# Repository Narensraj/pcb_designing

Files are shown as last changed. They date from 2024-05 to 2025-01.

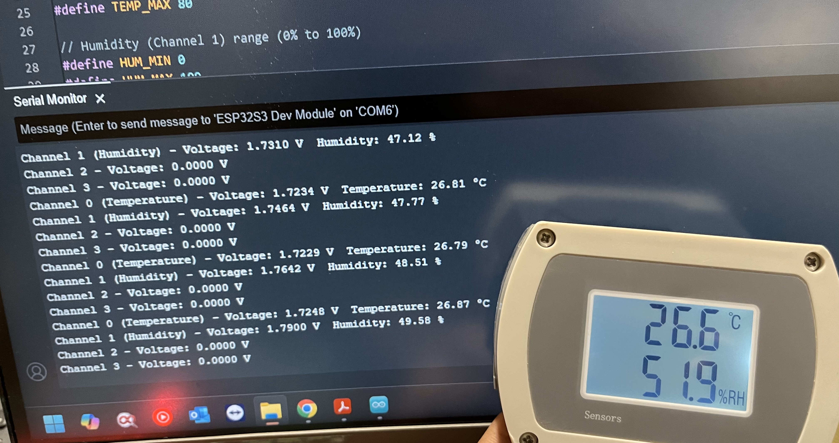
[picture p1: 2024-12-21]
Project_G/Test codes and examples/Analog_Input/TempHumid Sensor.jpg

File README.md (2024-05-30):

# ESP32 Relay Board

## Overview

This repository contains the design and documentation for an ESP32 relay board created using EasyEDA. It comprises various components such as AC to DC converter, voltage regulator, ESP32 microcontroller, USB to UART interface, relay control, RGB LED control, and miscellaneous components.

## Components

### AC to DC Converter

- **Module:** HLK-PM01
- **Output:** 5V from AC mains

### Voltage Regulator (AMS1117-3.3)

- **Function:** Converts 5V to 3.3V
- **Usage:** Provides power to the ESP32 and other 3.3V components

### Capacitors

- **Types:** Decoupling capacitors (220 µF, 10 µF, and 100 nF)
- **Purpose:** Stabilize the voltage supply around the voltage regulator

### ESP32 Microcontroller

- **Model:** ESP32-S3-WROOM-1 (U3)
- **Functionality:** Central microcontroller unit
- **Features:**
  - GPIO Connections for various components
  - Reset and Boot Buttons for manual control

### USB to UART Interface

- **Model:** CP2102-GMR (U16)
- **Functionality:** USB to UART bridge for programming and serial communication
- **Components:**
  - Includes RTS, DTR signals, and USB data lines (D+, D-)

### Relay Control

- **Relays:** ALQ105
- **Control:** GPIO pins through transistors (MMSS8050-H-TP) and optocouplers (CYPC817)
- **Supporting Components:** Transistors, resistors, and optocouplers for relay coil control and isolation

### RGB LED Control

- **LED Type:** WS2812B
- **Control:** Connected to a GPIO pin for RGB LED control

### Miscellaneous Components

- **Test Points:** Provided for 3.3V, 5V, and ground for easy debugging
- **Indicator LEDs:** With current limiting resistors to indicate power status and other signals
- **Mounting Holes:** For securing the PCB

## License

This project is licensed under no-one you can freely use the schematics and pcb layout.

And remember, when life throws you a relay, just switch it on and keep the circuit flowing! 😉🔌

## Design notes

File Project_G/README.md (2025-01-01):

# GController: ESP32-S3-Based Controller System

## Overview
The **GController** is a feature-rich embedded system designed using the **ESP32-S3** microcontroller. It integrates multiple peripherals, sensors, and interfaces, making it an ideal choice for industrial automation, IoT, and control system applications. This repository documents the hardware design, PCB layout, and related details for the GController system.

---

## Hardware Design

### PCB Specifications
- **Multi-layer PCB**:
  - Dedicated power and ground planes for noise reduction.
- **Connector Layouts**:
  - Clearly marked connections for peripherals, power, and sensors.
  - Separate connectors for high-current and low-current devices.
- **Thermal Considerations**:
  - Adequate spacing and heat management for power MOSFETs and regulators.

### Key ICs and Components

1. **Core Controller**:
   - **ESP32-S3-WROOM-1U-N16R8**: Dual-core processor with Wi-Fi, Bluetooth 5.0, and extensive GPIO support for SPI, I2C, UART, ADC, and DAC.  
     16 MB Flash and 8 MB PSRAM for seamless multitasking and data handling.

2. **Power Management**:
   - **XL4015**: High-efficiency buck converter for 12V output.
   - **XL1507 & B0505S**: 5V buck converter for powering isolated systems.
   - **ADM7172**: Low-dropout regulator for 3.3V output.
   - **LM74500**: Reverse polarity protection for stable operation.

3. **Communication Interfaces**:
   - **RS485** communication with **SP485EEN-L/TR** transceiver.
   - LoRa header for long-range wireless communication.
   - USB Type-C interface with ESD protection.

4. **Peripheral Interfaces**:
   - **Analog Inputs**: 4 channels (4-20mA) with **ADS1115** (16-bit ADC).
   - **Analog Outputs**: 2 channels (0-10V) driven by **GP8413** (15-bit DAC).
   - **Digital Inputs**: 6 optocoupler-based channels (EL357N), supporting 3-32V input.
   - **Digital Outputs**: 8 MOSFET-driven channels (IRF5305STRLPBF), handling 5-36V @ 5A, and 2 **ALQ105** Relay channels.

5. **Integrated Sensors and Storage**:
   - **BMP280**: Onboard temperature and pressure monitoring.
   - **DS3231 RTC**: Real-time clock for precise scheduling.
   - **Storage**:
     - **W25N01GVZEIG** SPI NAND Flash.
     - SD card slot for extended storage.

6. **User Interface**:
   - 7-inch touchscreen support with dedicated connector.
   - RGB LED indicators (WS2812B) for system status.
   - Built-in buzzer for notifications.

7. **Pilot Lamps and Headers**:
   - Pilot lamps for "Running," "Alarm," and "Stopped" statuses.
   - Dedicated headers for power, UART, and LoRa.

---

## Documentation
- [Schematic](./Documents/Schematic.pdf)
- [PCB Layout](./Documents/PCB.pdf)

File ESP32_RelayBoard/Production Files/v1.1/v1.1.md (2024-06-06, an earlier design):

# v1.1

Couple of traces had acute angle. Which is been changed to 45°.

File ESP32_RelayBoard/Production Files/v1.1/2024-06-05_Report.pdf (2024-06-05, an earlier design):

## HQDFM Design for Manufacture(DFM) Report

### File name: 2024-06-05

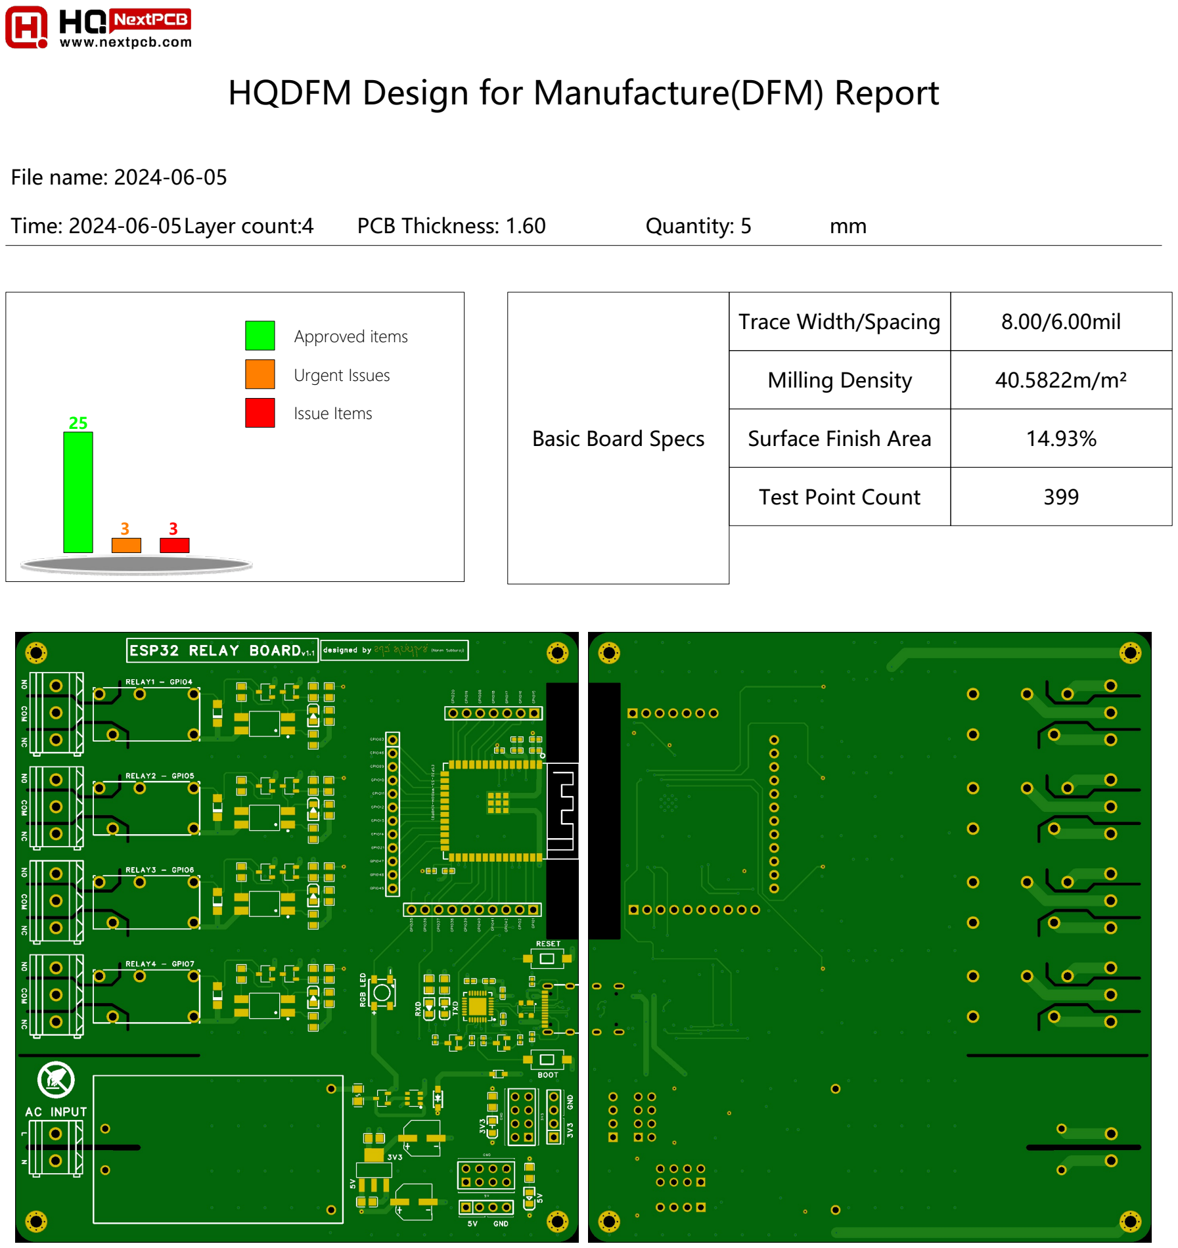
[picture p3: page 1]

Time: 2024-06-05Layer count:4 | PCB Thickness: 1.60 | Quantity: 5
mm

Approved items

Urgent Issues

Issue Items 25

3 3

Basic Board Specs | Trace Width/Spacing | 8.00/6.00mil
| Milling Density | 40.5822m/m²
| Surface Finish Area | 14.93%
| Test Point Count | 399

Type | Category | No. of Checks | Result
| Open/Shorts (IPC) | 1 | Fail
| Signal Integrity | 4 | Pass
| Smallest Trace Width | 1 | Pass 3
| Smallest Trace Spacing | 3 | Pass 161
| SMD Pad Spacing | 1 | Pass
| Pad Size | 3 | Pass 30
| Hatched Copper Pour | 2 | Pass
| Annular Ring Size | 2 | Pass 6 , Fail 1
| Drill to Copper | 5 | Pass 630 , Fail 2
| Copper-to-Board Edge | 2 | Pass 132 , Fail 34
| Holes on SMD Pads | 4 | Pass
PCB Drilling Analysis | Drill Diameter | 8 | Pass 41 , Fail 1
| Drill Spacing | 4 | Pass 18
| Drill to Board Edge | 4 | Pass
| Drill Hole Density | 1 | Pass
| Special Drill Holes | 2 | Pass
| Drill Hole Errors | 3 | Pass
PCB Solder Mask Analysis | Solder Mask Dam | 2 | Pass 12
| Missing SMask Opening | 1 | Pass
| Solder Paste Area | 1 | Pass
PCB Silk Analysis | Silkscreen Spacing | 1 | Pass 5 , Fail 14

PCB Trace Analysis

PCBA Component Analysis | Component Spacing | 1 | Fail
| Comp.-to-Board-Edge | 3 | Fail
| Componet Silkscreen Spacing | 0 | Fail
| Pad Count Mismatch | 2 | Fail
| Designator Length | 0 | Fail
| Double-sided Components | 1 | Pass
ComponentClearanceAnalysis | 1 | Pass
PCBA Pin Analysis | Pin-to-SMD Pad | 7 | Fail
| Through-hole Pins | 9 | Fail
| Pressfit Pins | 4 | Fail
PCBA Pad Analysis | Chip Pad | 60 | Fail
| Pad-Trace Connections | 4 | Pass 302 , Fail 44
PCBA Fiducial Analysis | Fiducial Count | 1 | Fail
| Fiducial Analysis | 3 | Pass

ID | Check | Limits | Value | Issue | Image | Position | Qty | Level

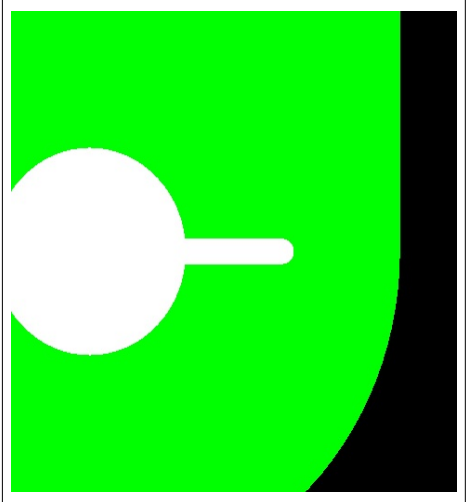
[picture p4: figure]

1

Annular

### Ring Size_PTH

Annular

### Ring

6,7,8

0.15

mm

PTH annular rings 6.10mil
mil in size were detected in your design. This could
increase the risk of
tangency or breakouts, which decrease

manufacturing efficiency
and yield, and affect the
reliability of the boards. It is recommended that PTH
Pad Rings have a width of
at least 6 mil.
96.98,-109.87 | 1 | Warnin g

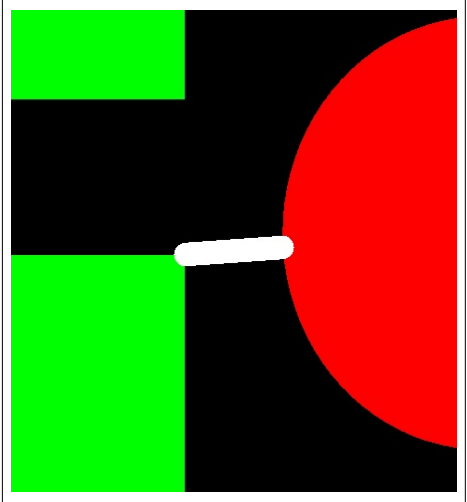
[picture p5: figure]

2

### Drill to

Copper_NP
TH-to- Copper

8,10,12

0.17

mm

The NPTH to copper
spacing should be at least

### 8 mil (ideally 12 mil). Spacing less than this could

increase the risk of defects such as exposed copper, which decrease

manufacturing efficiency
and yield, and affect the
reliability of the boards. The NPTH to copper

spacing in your design is
only 6.75mil. It is
recommended to increase
the spacing to at least 12 mil.
100.26,-73.95 | 1 | Risk

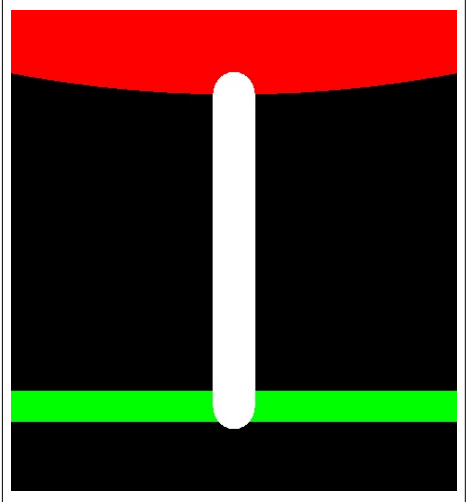
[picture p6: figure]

3

Copper-to- Board

### Edge_Cop

per-to- Board

### Edge

8,15,20

0.26

mm

Copper-to-edge spacing of
10.10mil was detected in
your design.This could
increase the risk of
exposed copper on the
edge of the boards or
damaged traces/pads, which decrease

manufacturing efficiency
and yield, and affect the
reliability of the boards. It is recommended to
increase the spacing to at least 0.4 mm for edge
routing and for v-cuts (v- cut spacing may depends

on board thickness).

15.82,-30.70 | 4 | Warnin
| | g

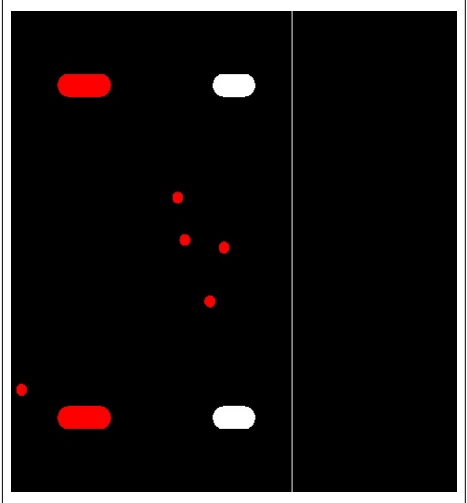
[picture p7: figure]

4

### Drill

Diameter_S
lot Aspect
Ratio

12,10,8

0.31

mm

Slots with aspect ratio of 2.00 were detected in your design. This could increase the risk of incomplete

### drilling of the slot, which

decrease manufacturing
efficiency and yield, and

### affect the reliability of the

boards. The ratio should be increased to at least 2:1

104.37,-71.03 | 1 | Warnin g

5

### Silkscre

e

n
S
p

acin
g

_

S

### old

er Mask-to- Silkscreen

4,5,6

0.0

0

m

# m For m ost factories, th

e
| minim
u

m silkscre
e

n to solder mask spacing requirement is at least 8 mil. Failure to meet the factory's requirements could result in part of the silkscreen being removed or being printed directly o

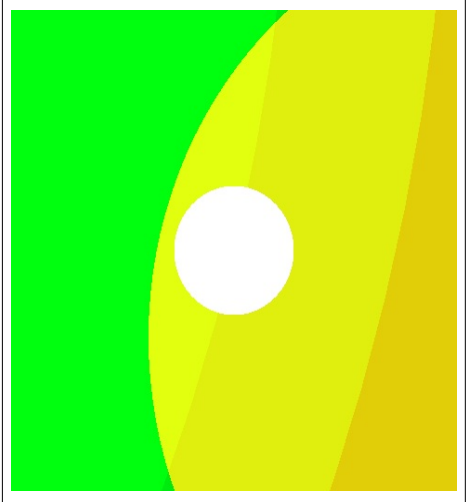
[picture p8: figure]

n the pads, which decrease manufacturing efficiency and yield, and affect the reliability of the boards. Silkscreen to solder mask spacing of 0 mil were detected in your design. It is recommended to increase the spacing to at least 12 mil. | 10
5.2

6,-7
5.5
0 | 1 | Risk

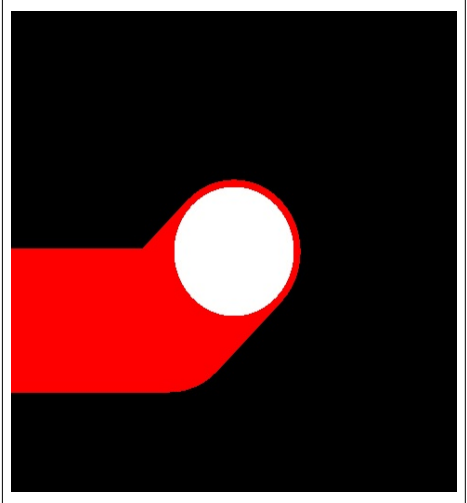
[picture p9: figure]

6

P
a

d-Trace
C
o

n

n

ectio

ns _

T

H

T
P
a
d-Trace Width | -,-,- | N ot analy

z
| | e
d | If th
e trace

width is gre
ater than 100.00% of the width of the solder pad, there will be increased thermal dissipation to the connected copper during soldering that may increase solder defects such as cold solder joints. It is recommended to reduce the trace width near the pad (necking down). | 16.9

5,-9

3.5

3

2

### Risk

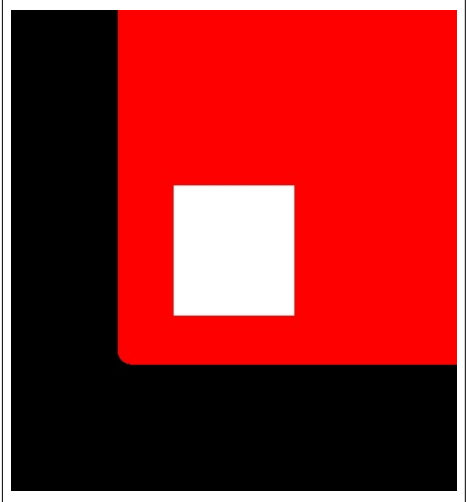
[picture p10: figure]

7

P
a

d-Trace
C
o

n

n

ectio

ns _

S
M

D
P
a
d-Trace Width | -,-,- | N ot analy

z
| | e
d | If th
e trace

width is gre
ater than 100.00% of the width of the solder pad, there will be increased thermal dissipation to the connected copper during soldering that may increase solder defects such as cold solder joints. It is recommended to reduce the trace width near the pad (necking down). | 8

9.4

7,-3

3.6
4

3
5

### Risk

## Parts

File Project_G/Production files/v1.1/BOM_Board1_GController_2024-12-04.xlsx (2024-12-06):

No. | Quantity | Comment | Designator | Footprint | Value | Manufacturer Part | Manufacturer | Supplier Part | Supplier | Layer
1 | 1 | CR2032-BS-6-1 | B1 | BAT-TH_CR2032-BS-6-1 |  | CR2032-BS-6-1 | Q&J | C70377 | LCSC | T
2 | 1 | 2.7kHz | BUZZER1 | BUZ-SMD_4P-L8.5-W8.5-P8.50-BR | 2.7kHz | MLT-8530 | 华能 | C94599 | LCSC | T
3 | 1 | 4.7nF | C1 | C1206 | 4.7nF | 1206B472K102NT | FH(风华) | C9192 | LCSC | T
4 | 4 | 1uF | C2,C7,C9,C11 | C0805 | 1uF | 0805B105K500NT | FH(风华) | C215803 | LCSC | T
5 | 2 | 330nF | C3,C16 | C1206 | 330nF | CC1206KRX7R9BB334 | YAGEO(国巨) | C274377 | LCSC | T
6 | 2 | 100nF | C4,C73 | C0603 | 100nF | CL10B104KA8NNNC | SAMSUNG(三星) | C1590 | LCSC | T
7 | 2 | 2.2uF | C5,C74 | C1210 | 2.2uF | CL32B225KCJSNNE | SAMSUNG(三星) | C55151 | LCSC | T
8 | 2 | 220uF | C6,C75 | CAP-SMD_BD10.0-L10.3-W10.3-LS11.3-FD | 220uF | RVT1H221M1010 | ROQANG(容强) | C72499 | LCSC | T
9 | 1 | 330uF | C8 | CAP-SMD_BD6.3-L6.6-W6.6-LS7.3-FD | 330uF | GVM1E331M0607 | HONOR(荣誉) | C2980171 | LCSC | T
10 | 1 | 470uF | C10 | CAP-SMD_BD12.5-L13.0-W13.0-FD | 470uF | VT1H471MI135000CE0 | HUAWEI(华威集团) | C191227 | LCSC | T
11 | 1 | 330uF | C12 | CAP-SMD_BD10.0-L10.3-W10.3-LS11.3-FD | 330uF | RVE1V331M1010 | HONOR(荣誉) | C88682 | LCSC | T
12 | 2 | 10uF | C13,C14 | C0805 | 10uF | CL21A106KOQNNNE | SAMSUNG(三星) | C1713 | LCSC | T
13 | 1 | 100nF | C15 | C0805 | 100nF | C0805B104K500NT | TORCH(火炬) | C476766 | LCSC | T
14 | 2 | 4.7uF | C17,C18 | C0805 | 4.7uF | HGC0805R7475K500NSLJ | Chinocera(华瓷) | C7472970 | LCSC | T
15 | 15 | 1uF | C19,C21,C23,C24,C28,C31,C32,C36,C37,C39,C44,C46,C55,C60,C68 | C0603 | 1uF | C0603X5R105K250NT | SANYEAR(叁叶源) | C466771 | LCSC | T
16 | 7 | 100nF | C20,C22,C25,C27,C29,C33,C35 | C0603 | 100nF | CC0603KRX7R9BB104 | YAGEO(国巨) | C14663 | LCSC | T
17 | 3 | 10uF | C26,C30,C34 | C0805 | 10uF | CL21A106KAYNNNE | SAMSUNG(三星) | C15850 | LCSC | T
18 | 14 | 100nF | C38,C45,C47,C48,C49,C50,C52,C54,C57,C59,C61,C69,C70,C71 | C0603 | 100nF | CL10B104KB8NNNC | SAMSUNG(三星) | C1591 | LCSC | T
19 | 3 | 100nF | C40,C43,C64 | C0402 | 100nF | GRM155R71H104KE14D | muRata(村田) | C77020 | LCSC | T
20 | 2 | 10uF | C41,C42 | C0402 | 10uF | CL05A106MQ5NUNC | SAMSUNG(三星) | C15525 | LCSC | T
21 | 1 | 1nF | C51 | C0603 | 1nF | 0603B102K101CT | Walsin(华新科) | C77438 | LCSC | T
22 | 1 | 1nF | C53 | C1206 | 1nF | GR431BR7LA102KW66L | muRata(村田) | C161353 | LCSC | T
23 | 2 | 10uF | C56,C58 | C0603 | 10uF | GRM188R61E106KA73D | muRata(村田) | C344022 | LCSC | T
24 | 4 | 10pF | C62,C63,C66,C67 | C0603 | 10pF | CC0603JRNPO9BN100 | YAGEO(国巨) | C106245 | LCSC | T
25 | 1 | 1uF | C65 | C0402 | 1uF | HGC0402R5105K250NTEJ | Chinocera(华瓷) | C7472946 | LCSC | T
26 | 2 | 330nF | C72,C76 | C1206 | 330nF | 1206B334K500NT | FH(风华) | C1865 | LCSC | T
27 | 1 | DB2ERC-5.08-3P-OG | CN1 | CONN-TH_3P-P5.08_DB2ERC-5.08-3P-OG |  | DB2ERC-5.08-3P-OG | DORABO(地博电气) | C430435 | LCSC | T
28 | 23 | DB2ERC-5.08-2P-GN | CN2,CN3,CN4,CN5,CN6,CN7,CN8,CN9,CN10,CN11,CN12,CN13,CN14,CN15,CN16,CN17,CN18,CN19,CN20,CN21,CN24,CN25,CN26 | CONN-TH_2P-P5.08_DB2ERC-5.08-2P |  | DB2ERC-5.08-2P-GN | DORABO(地博电气) | C395737 | LCSC | T
29 | 2 | DB2ERC-5.08-3P-BK | CN22,CN23 | CONN-TH_3P-P5.08_DB2ERC-5.08-3P-BK |  | DB2ERC-5.08-3P-BK | DORABO(地博电气) | C430440 | LCSC | T
30 | 2 | PMEG6030ETPX | D1,D3 | SOD-128_L3.7-W2.5-LS4.7-RD |  | PMEG6030ETPX | Nexperia(安世) | C458168 | LCSC | T
31 | 1 | PRTR5V0U2X,215 | D2 | SOT-143_L2.9-W1.3-P1.92-LS2.3-BR |  | PRTR5V0U2X,215 | Nexperia(安世) | C12333 | LCSC | T
32 | 2 | SMBJ33CA | D4,D42 | SMB_L4.3-W3.6-LS5.4-BI |  | SMBJ33CA | Brightking(君耀电子) | C78420 | LCSC | T
33 | 1 | B540C-13-F | D5 | SMC_L7.1-W6.2-LS8.1-RD |  | B540C-13-F | DIODES(美台) | C72264 | LCSC | T
34 | 1 | B330B-13-F | D6 | SMB_L4.6-W3.6-LS5.3-RD |  | B330B-13-F | DIODES(美台) | C134450 | LCSC | T
35 | 1 | BZT52C6V8S | D7 | SOD-323_L1.8-W1.3-LS2.5-RD |  | BZT52C6V8S | BORN(伯恩半导体) | C266580 | LCSC | T
36 | 2 | BAT54S | D8,D11 | SOT-23-3_L2.9-W1.3-P1.90-LS2.4-BR |  | BAT54S | JSMSEMI(杰盛微) | C916425 | LCSC | T
37 | 2 | 1N5819W | D9,D12 | SOD-123_L2.8-W1.8-LS3.7-RD |  | 1N5819W | TWGMC(台湾迪嘉) | C727115 | LCSC | T
38 | 1 | BZT52C18S | D10 | SOD-323_L1.8-W1.3-LS2.5-RD |  | BZT52C18S | MDD | C173446 | LCSC | T
39 | 1 | LL4148 | D13 | LL-34_L3.5-W1.5-RD |  | LL4148 | MDD(辰达半导体) | C435829 | LCSC | T
40 | 1 | SMAJ6.5CA | D14 | SMA_L4.3-W2.6-LS5.1-BI |  | SMAJ6.5CA | FTR(乔光电子) | C693489 | LCSC | T
41 | 1 | SM712 | D15 | SOT-23-3_L2.9-W1.6-P1.90-LS2.8-BR |  | SM712 | MDD | C502564 | LCSC | T
42 | 1 | 3RL150M-5-S | D16 | DIO-DT-SMD_3P-BD5.0-L7.2-P3.30 |  | 3RL150M-5-S | Brightking(君耀电子) | C522540 | LCSC | T
43 | 4 | BAT54S,215 | D17,D18,D21,D22 | SOT-23-3_L3.0-W1.7-P0.95-LS2.9-BR |  | BAT54S,215 | Nexperia(安世) | C47546 | LCSC | T
44 | 4 | SMAJ33A | D19,D20,D23,D24 | SMA_L4.3-W2.6-LS5.2-RD |  | SMAJ33A | 晶导微电子 | C353454 | LCSC | T
45 | 2 | SMBJ12A | D25,D26 | SMB_L4.6-W3.6-LS5.3-RD |  | SMBJ12A | GOODWORK(固得沃克) | C908793 | LCSC | T
46 | 6 | CD4148WSP | D27,D28,D29,D30,D31,D32 | D0805-RD |  | CD4148WSP | LIZ(丽智电子) | C109001 | LCSC | T
47 | 11 | SS54 | D33,D34,D35,D36,D37,D38,D39,D40,D45,D46,D47 | SMA_L4.4-W2.8-LS5.4-R-RD |  | SS54 | MDD(辰达半导体) | C22452 | LCSC | T
48 | 2 | FDLL4148 | D41,D43 | SOD-80_L3.5-W1.5-RD |  | FDLL4148 | onsemi(安森美) | C78608 | LCSC | T
49 | 1 | 1N4148WS | D44 | SOD-323_L1.8-W1.3-LS2.5-RD |  | 1N4148WS | SHIKUES(时科) | C110221 | LCSC | T
50 | 2 | BSMD1206-020-30V | F1,F2 | F1206 |  | BSMD1206-020-30V | BHFUSE(佰宏) | C883118 | LCSC | T
51 | 1 | FPC-05FB-60PH20 | FPC1 | FPC-SMD_60P-P0.50_FPC-05FB-60PH20 |  | FPC-05FB-60PH20 | XUNPU(讯普) | C2856839 | LCSC | T
52 | 4 | 2.54-1*3P针 | H1,H2,H3,H4 | HDR-TH_3P-P2.54-V-M-1 |  | 2.54-1*3P针 | BOOMELE(博穆精密) | C49257 | LCSC | T
53 | 2 | ALQ105 | K1,K2 | RELAY-TH_ALQ1XX |  | ALQ105 | PANASONIC(松下) | C719517 | LCSC | T
54 | 1 | 33uH | L1 | IND-SMD_L12.0-W12.0 | 33uH | SLH1207S330MTT | Sunltech(韩国顺磁) | C181844 | LCSC | T
55 | 1 | 22uH | L2 | IND-SMD_L4.9-W4.9_NRS50XX | 22uH | NRS5020T220MMGJV | TAIYO YUDEN(太诱) | C515385 | LCSC | T
56 | 6 | LTST-C170TBKT | LED1,LED2,LED3,LED4,LED5,LED6 | LED0805-RD_BLUE |  | LTST-C170TBKT | LITEON(光宝) | C98222 | LCSC | T
57 | 13 | NCD0805R1 | LED7,LED8,LED9,LED10,LED11,LED12,LED13,LED14,LED15,LED17,LED28,LED29,LED30 | LED0805-R-RD |  | NCD0805R1 | 国星光电 | C84256 | LCSC | T
58 | 8 | 17-215SURC/S530-A2/TR8 | LED16,LED18,LED19,LED20,LED21,LED22,LED23,LED25 | LED0805-RD_RED |  | 17-215SURC/S530-A2/TR8 | EVERLIGHT(亿光) | C142306 | LCSC | T
59 | 2 | SZYY0805YG | LED24,LED26 | LED0805-R-RD_GREEN |  | SZYY0805YG | yongyu(永裕光电) | C434435 | LCSC | T
60 | 1 | XL-5050RGBC-WS2812B | LED27 | LED-SMD_4P-L5.0-W5.0-BL_XL-5050RGBC |  | XL-5050RGBC-WS2812B | XINGLIGHT(成兴光) | C2843785 | LCSC | T
61 | 2 | DMT6005LPS-13 | Q1,Q18 | DFN-8_L6.0-W5.1-P1.27-LS6.2-BL |  | DMT6005LPS-13 | DIODES(美台) | C780843 | LCSC | T
62 | 11 | IRF5305STRLPBF | Q2,Q3,Q4,Q8,Q9,Q10,Q14,Q15,Q23,Q25,Q27 | TO-263-2_L10.0-W9.1-P5.08-LS15.2-TL |  | IRF5305STRLPBF | Infineon(英飞凌) | C41224 | LCSC | T
63 | 15 | MMSS8050-L-TP | Q5,Q6,Q7,Q11,Q12,Q13,Q16,Q17,Q19,Q20,Q21,Q22,Q24,Q26,Q28 | SOT-23-3_L2.9-W1.3-P1.90-LS2.4-BR |  | MMSS8050-L-TP | MCC(美微科) | C194044 | LCSC | T
64 | 1 | 1MΩ | R1 | R0402 | 1MΩ | ERJ2RKF1004X | PANASONIC(松下) | C413126 | LCSC | T
65 | 2 | 5.1kΩ | R2,R3 | R0402 | 5.1kΩ | RMC04025.1K1%N | Tyohm(幸亚电阻) | C325521 | LCSC | T
66 | 1 | 47kΩ | R4 | R0805 | 47kΩ | CR0805J80473G | LIZ(丽智电子) | C102018 | LCSC | T
67 | 1 | 13kΩ | R5 | R0805 | 13kΩ | ERA6AEB133V | PANASONIC(松下) | C445658 | LCSC | T
68 | 14 | 1kΩ | R6,R8,R84,R87,R90,R102,R105,R108,R118,R121,R136,R151,R157,R163 | R0603 | 1kΩ | RC0603FR-071KL | YAGEO(国巨) | C22548 | LCSC | T
69 | 30 | 10kΩ | R7,R14,R18,R21,R24,R25,R26,R28,R29,R30,R34,R37,R38,R39,R40,R41,R46,R47,R83,R86,R89,R101,R104,R107,R117,R120,R137,R149,R156,R162 | R0603 | 10kΩ | RC0603FR-0710KL | YAGEO(国巨) | C98220 | LCSC | T
70 | 1 | 47kΩ | R9 | R0603 | 47kΩ | RC0603FR-0747KL | YAGEO(国巨) | C105579 | LCSC | T
71 | 1 | 4.7kΩ | R10 | R0603 | 4.7kΩ | ERA3VEB4701V | PANASONIC(松下) | C490795 | LCSC | T
72 | 2 | 1.8Ω | R11,R12 | R0805 | 1.8Ω | RC0805FR-071R8L | YAGEO(国巨) | C482990 | LCSC | T
73 | 1 | 15kΩ | R13 | R0603 | 15kΩ | RT0603BRD0715KL | YAGEO(国巨) | C326733 | LCSC | T
74 | 1 | 10kΩ | R15 | RES-ADJ-SMD_3P-L3.0-W3.8-P1.75-BR | 10kΩ | TC33X-2-103E | BOURNS | C719176 | LCSC | T
75 | 9 | 4.7kΩ | R16,R19,R20,R33,R35,R36,R50,R51,R52 | R0603 | 4.7kΩ | RC0603FR-074K7L | YAGEO(国巨) | C99782 | LCSC | T
76 | 1 | 6.8kΩ | R17 | R0603 | 6.8kΩ | RC0603JR-076K8L | YAGEO(国巨) | C127446 | LCSC | T
77 | 4 | 10kΩ | R22,R23,R42,R43 | R0603 | 10kΩ | CR0603FA1002G | LIZ(丽智电子) | C126901 | LCSC | T
78 | 1 | 10kΩ | R27 | R0402 | 10kΩ | RC0402FR-0710KL | YAGEO(国巨) | C60490 | LCSC | T
79 | 1 | 56kΩ | R31 | R0603 | 56kΩ | PTFR0603B56K0P9 | RESI(开步睿思) | C351640 | LCSC | T
80 | 1 | 120Ω | R32 | R0603 | 120Ω | 0603WAF1200T5E | UNI-ROYAL(厚声) | C22787 | LCSC | T
81 | 4 | 150Ω | R44,R45,R48,R49 | R0603 | 150Ω | AR03BTCX1500 | Viking(光颉) | C319859 | LCSC | T
82 | 6 | 4.7kΩ | R53,R54,R61,R62,R69,R70 | R0805 | 4.7kΩ | RS-05K472JT | FH(风华) | C115310 | LCSC | T
83 | 6 | 100Ω | R55,R56,R63,R64,R71,R73 | R0805 | 100Ω | RTT05101JTP | RALEC(旺诠) | C103909 | LCSC | T
84 | 12 | 10kΩ | R57,R58,R59,R60,R65,R66,R67,R68,R72,R74,R75,R76 | R0805 | 10kΩ | 0805W8F1002T5E | UNI-ROYAL(厚声) | C17414 | LCSC | T
85 | 28 | 4.7kΩ | R77,R78,R80,R85,R88,R92,R95,R97,R99,R103,R106,R110,R113,R115,R119,R123,R125,R127,R130,R131,R133,R135,R147,R150,R153,R155,R159,R161 | R0805 | 4.7kΩ | 0805W8F4701T5E | UNI-ROYAL(厚声) | C17673 | LCSC | T
86 | 13 | 2kΩ | R79,R81,R82,R96,R98,R100,R114,R116,R126,R132,R148,R154,R160 | R0805 | 2kΩ | 0805W8F2001T5E | UNI-ROYAL(厚声) | C17604 | LCSC | T
87 | 13 | 100kΩ | R91,R93,R94,R109,R111,R112,R122,R124,R129,R134,R152,R158,R164 | R0805 | 100kΩ | 0805W8F1003T5E | UNI-ROYAL(厚声) | C149504 | LCSC | T
88 | 2 | 4.7kΩ | R128,R142 | R1206 | 4.7kΩ | 1206W4F4701T5E | UNI-ROYAL(厚声) | C17936 | LCSC | T
89 | 1 | 270Ω | R138 | R0805 | 270Ω | RC0805FR-07270RL | YAGEO(国巨) | C137558 | LCSC | T
90 | 2 | 620Ω | R139,R140 | R0805 | 620Ω | 0805W8F6200T5E | UNI-ROYAL(厚声) | C17782 | LCSC | T
91 | 1 | 2.2kΩ | R141 | R1206 | 2.2kΩ | RC1206FR-072K2L | YAGEO(国巨) | C114933 | LCSC | T
92 | 4 | 1kΩ | R143,R144,R145,R146 | R0805 | 1kΩ | 0805W8J0102T5E | UNI-ROYAL(厚声) | C25623 | LCSC | T
93 | 2 | TS-1101S-C-B-B-B-A | SW1,SW2 | SW-SMD_L6.0-W3.5-LS8.0 |  | TS-1101S-C-B-B-B-A | XKB Connectivity(中国星坤) | C609852 | LCSC | T
94 | 10 | 2AS3T1A1M2QES | SW3,SW4,SW5,SW6,SW7,SW8,SW9,SW10,SW11,SW12 | SW-TH_2AS3T1A1M2QES |  | 2AS3T1A1M2QES | Dailywell(德利威) | C908284 | LCSC | T
95 | 5 | RH-5000 | U1,U2,U4,U6,U13 | TEST-TH_BD2.54-P1.4_RED |  | RH-5000 | 荣和 | C5277086 | LCSC | T
96 | 1 | SS-12M10G5 | U3 | SW-TH_XKB_SS-12M10G5 |  | SS-12M10G5 | XKB Connection(中国星坤) | C2884788 | LCSC | T
97 | 1 | B0505S-3WR2 | U5 | PWRM-TH_B0505S-3WR2 |  | B0505S-3WR2 | YLPTEC(易川) | C5369498 | LCSC | T
98 | 2 | DBT50G-9.5-2P-BK-P OGC | U7,U50 | CONN-TH_2P-P9.50_DBT50G-9.5-2P |  | DBT50G-9.5-2P-BK-P OGC | DORABO(地博电气) | C395958 | LCSC | T
99 | 1 | XL4015E1 | U8 | TO-263-5_L10.2-W8.9-P1.70-TL |  | XL4015E1 | XLSEMI(芯龙) | C51661 | LCSC | T
100 | 1 | XL1507-5.0E1 | U9 | TO-252-5_L6.5-W5.6-P1.27-LS9.5-TL |  | XL1507-5.0E1 | XLSEMI(芯龙) | C74195 | LCSC | T
101 | 1 | 47uH | U10 | IND-SMD_L13.5-W12.5 | 47uH | CXP1265-470M-HG(47UH) | DMBJ(振宝佳) | C7461747 | LCSC | T
102 | 2 | LM74500QDDFRQ1 | U11,U51 | SOT-23-8_L3.0-W1.7-P0.65-LS2.8-BR |  | LM74500QDDFRQ1 | TI(德州仪器) | C5219210 | LCSC | T
103 | 1 | 1.5kΩ | U12 | R0805 | 1.5kΩ | ARG05BTC1501 | Viking(光颉) | C2828734 | LCSC | T
104 | 1 | ADM7172ACPZ-3.3-R7 | U14 | DFN-8_L3.0-W3.0-P0.50-BL-EP |  | ADM7172ACPZ-3.3-R7 | ADI(亚德诺) | C514342 | LCSC | T
105 | 1 | 1nF | U15 | C0805 | 1nF | FCC0805B102K102FT | FOJAN(富捷) | C5137645 | LCSC | T
106 | 1 | 10uH | U16 | IND-SMD_L4.4-W4.2_BCIHP0412SC | 10uH | BCIHP0420SC-100M | BC(台湾诚阳) | C2921170 | LCSC | T
107 | 1 | AP3032KTR-G1 | U17 | SOT-23-6_L2.9-W1.6-P0.95-LS2.8-BR | - | AP3032KTR-G1 | DIODES(美台) | C264086 | LCSC | T
108 | 1 | AP3012KTR-G1 | U18 | TSOT-23-5_L2.9-W1.6-P0.95-LS2.8-BL |  | AP3012KTR-G1 | DIODES(美台) | C102618 | LCSC | T
109 | 1 | 33kΩ | U19 | R0603 | 33kΩ | HPCR0603F33K0K9 | RESI(开步睿思) | C365146 | LCSC | T
110 | 1 | ESP32-S3-WROOM-1U-N16R8 | U20 | WIRELM-SMD_ESP32-S3-WROOM-1U |  | ESP32-S3-WROOM-1U-N16R8 | ESPRESSIF(乐鑫) | C3013946 | LCSC | T
111 | 1 | LTC4311CSC6#TRPBF | U21 | SC-70-6_L2.1-W1.3-P0.65-LS2.1-BR |  | LTC4311CSC6#TRPBF | ADI(亚德诺) | C580856 | LCSC | T
112 | 2 | MCP23017T-E/ML | U22,U23 | QFN-28_L6.0-W6.0-P0.65-BL-EP3.7 |  | MCP23017T-E/ML | MICROCHIP(美国微芯) | C629439 | LCSC | T
113 | 1 | 74HC04D | U24 | SOIC-14_L8.7-W3.9-P1.27-LS6.0-BL |  | 74HC04D | FM(富满) | C86613 | LCSC | T
114 | 1 | π141E61Q | U25 | WSOIC-16_L10.3-W7.5-P1.27-LS10.3-BL |  | π141E61Q | 2Pai Semi(荣湃) | C6807845 | LCSC | T
115 | 1 | SP485EEN-L/TR | U26 | SOIC-8_L5.0-W4.0-P1.27-LS6.0-BL |  | SP485EEN-L/TR | MaxLinear(迈凌) | C6855 | LCSC | T
116 | 2 | SMAJ12CA | U27,U28 | SMA_L4.3-W2.7-LS5.1-BI |  | SMAJ12CA | UMW(友台半导体) | C3001959 | LCSC | T
117 | 1 | DS3231SN# | U29 | SOIC-16_L10.3-W7.5-P1.27-LS10.3-BL |  | DS3231SN# | ADI(亚德诺)/MAXIM(美信) | C722469 | LCSC | T
118 | 1 | W25N01GVZEIG | U30 | WSON-8_L8.0-W6.10-P1.27-BL-EP |  | W25N01GVZEIG | WINBOND(华邦) | C907680 | LCSC | T
119 | 1 | KH-TF-07DT | U31 | SIM-SMD_C9900007362 |  | KH-TF-07DT | kinghelm(金航标) | C4943323 | LCSC | T
120 | 1 | BMP280 | U32 | LGA-8_L2.5-W2.0-P0.65_AMP6127 |  | BMP280 | Bosch(博世) | C83291 | LCSC | T
121 | 1 | ADS1115IDGSR | U33 | MSOP-10_L3.0-W3.0-P0.50-LS5.0-BL |  | ADS1115IDGSR | TI(德州仪器) | C37593 | LCSC | T
122 | 1 | GP8413-TC50-EW | U34 | ESOP-10_L4.9-W3.9-P1.00-LS6.0-BL-EP |  | GP8413-TC50-EW | Guestgood(客益) | C5464816 | LCSC | T
123 | 6 | EL357N(B)(TA)-G | U35,U36,U37,U38,U39,U40 | OPTO-SMD-4_L4.4-W4.1-P2.54-LS7.0-TL |  | EL357N(B)(TA)-G | EVERLIGHT(亿光) | C6649 | LCSC | T
124 | 13 | CYPC817(C-TP2) | U41,U42,U43,U44,U45,U46,U47,U48,U49,U52,U54,U55,U56 | SOP-4_L6.4-W4.6-P2.54-LS10.2-TL |  | CYPC817(C-TP2) | OCIC(卓睿科) | C385058 | LCSC | T
125 | 1 | SS8050 | U53 | SOT-23-3_L2.9-W1.3-P1.90-LS2.4-BR |  | SS8050 | HXY MOSFET(华轩阳电子) | C5184428 | LCSC | T
126 | 1 | PM254-2-10-Z-8.5 | U57 | HDR-TH_20P-P2.54-V-F-R2-C10-S2.54 |  | PM254-2-10-Z-8.5 | HCTL(华灿天禄) | C2897411 | LCSC | T
127 | 1 | PM254-2-06-Z-8.5 | U58 | HDR-TH_12P-P2.54-V-F-R2-C6-S2.54 |  | PM254-2-06-Z-8.5 | HCTL(华灿天禄) | C2897407 | LCSC | T
128 | 1 | TYPE-C 16PIN 2MD(073) | USB1 | USB-C-SMD_TYPE-C-6PIN-2MD-073 |  | TYPE-C 16PIN 2MD(073) | SHOU HAN(首韩) | C2765186 | LCSC | T

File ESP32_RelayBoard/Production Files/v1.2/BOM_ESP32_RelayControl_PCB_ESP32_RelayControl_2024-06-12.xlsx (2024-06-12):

No. | Quantity | Comment | Designator | Footprint | Value | Manufacturer Part | Manufacturer | Supplier Part | Supplier | Layer
1 | 2 | TS-1101S-C-B-B-B-A | BOOT,RESET | SW-SMD_L6.0-W3.5-LS8.0 |  | TS-1101S-C-B-B-B-A | XKB Connectivity(中国星坤) | C609852 | LCSC | T
2 | 1 | 10uF | C1 | C0402 |  | CC0402MRX5R5BB106 | YAGEO(国巨) | C105884 | LCSC | T
3 | 4 | 100nF | C2,C4,C6,C8 | C0402 |  | CSA0402X7R104K250GT | HRE(芯声) | C3015120 | LCSC | T
4 | 3 | 1uF | C3,C5,C7 | C0402 |  | HGC0402R5105K500NTEJ | Chinocera(华瓷) | C7472948 | LCSC | T
5 | 2 | 220uF | C9,C12 | CAP-SMD_BD6.3-L6.6-W6.6-LS7.2-FD |  | MVG 16V 220UF 6.3*7.7 | SAMYOUNG(韩国三莹) | C2827940 | LCSC | T
6 | 2 | 10uF | C10,C11 | C0805 |  | 0805F106M160NT | FH(风华) | C90545 | LCSC | T
7 | 4 | FDLL4148 | D1,D2,D3,D4 | SOD-80_L3.5-W1.5-RD |  | FDLL4148 | onsemi(安森美) | C78608 | LCSC | T
8 | 1 | 1N5819HW | D5 | SOD-123_L2.7-W1.6-LS3.7-RD-1 |  | 1N5819HW | TECH PUBLIC(台舟) | C2905649 | LCSC | T
9 | 1 | B5819WS_C22624 | D6 | SOD-323_L1.8-W1.3-LS2.5-RD |  | B5819WS | CJ(江苏长电/长晶) | C22624 | LCSC | T
10 | 1 | SP0503BAHTG_C3040626 | D7 | SOT-143-4_L2.9-W1.3-P1.92-LS2.4-BL |  | SP0503BAHTG | TECH PUBLIC(台舟) | C3040626 | LCSC | T
11 | 1 | BSMD0805-100-6V | F1 | F0805 |  | BSMD0805-100-6V | BHFUSE(佰宏) | C883112 | LCSC | T
12 | 5 | SZYY0805YG | GREEN,GREEN1,GREEN2,GREEN3,RX | LED0805-R-RD_GREEN |  | SZYY0805YG | yongyu(永裕光电) | C434435 | LCSC | T
13 | 4 | ALQ105 | K1,K2,K3,K4 | RELAY-TH_ALQ1XX |  | ALQ105 | PANASONIC(松下) | C719517 | LCSC | T
14 | 1 | FC-2012HYK-588J | LED1 | LED0805-R-RD |  | NCD0805Y1 | 国星光电 | C84261 | LCSC | T
15 | 1 | FC-2012YOXK(5)-600H08 | LED2 | LED0805-RD_ORANGE |  | NCD0805O1 | 国星光电 | C84262 | LCSC | T
16 | 8 | MMSS8050-H-TP | Q1,Q2,Q3,Q4,Q5,Q6,Q7,Q8 | SOT-23-3_L2.9-W1.6-P1.90-LS2.8-BR |  | MMSS8050-H-TP | MCC(美微科) | C90158 | LCSC | T
17 | 2 | L8050QLT1G | Q9,Q11 | SOT-23-3_L2.9-W1.3-P1.90-LS2.4-BR |  | L8050QLT1G | LRC(乐山无线电) | C49581 | LCSC | T
18 | 1 | FDN306P | Q10 | SOT-23-3_L3.0-W1.7-P0.95-LS2.9-BR |  | FDN306P | onsemi(安森美) | C154510 | LCSC | T
19 | 12 | 4.7kΩ | R2,R3,R6,R7,R8,R9,R14,R15,R18,R19,R21,R22 | R0805 |  | 0805W8F4701T5E | UNI-ROYAL(厚声) | C17673 | LCSC | T
20 | 4 | 2kΩ | R4,R5,R16,R17 | R0805 |  | 0805W8F2001T5E | UNI-ROYAL(厚声) | C17604 | LCSC | T
21 | 4 | 100kΩ | R10,R11,R23,R24 | R0805 |  | 0805W8F1003T5E | UNI-ROYAL(厚声) | C149504 | LCSC | T
22 | 4 | 10kΩ | R12,R13,R29,R30 | R0402 |  | RT0402DRE0710KL | YAGEO(国巨) | C326912 | LCSC | T
23 | 1 | 340Ω | R20 | R0805 |  | CR0805F83400G | LIZ(丽智电子) | C101671 | LCSC | T
24 | 1 | 147Ω | R25 | R0805 |  | CR0805-FX-1470ELF | BOURNS | C203753 | LCSC | T
25 | 2 | 1kΩ | R26,R27 | R0805 |  | RMC08051K5%N | Tyohm(幸亚电阻) | C269727 | LCSC | T
26 | 2 | 0Ω | R28,R31 | R0402 |  | RC0402FR-070RL | YAGEO(国巨) | C106231 | LCSC | T
27 | 2 | 5.1kΩ | R32,R33 | R0402 |  | RMC04025.1K1%N | Tyohm(幸亚电阻) | C325521 | LCSC | T
28 | 1 | XL-5050RGBC-WS2812B | RGB | LED-SMD_4P-L5.0-W5.0-BL_XL-5050RGBC |  | XL-5050RGBC-WS2812B | XINGLIGHT(成兴光) | C2843785 | LCSC | T
29 | 1 | 17-215SURC/S530-A2/TR8(TY) | TX | LED0805-RD_RED |  | 17-215SURC/S530-A2/TR8 | EVERLIGHT(亿光) | C142306 | LCSC | T
30 | 4 | DB128L-5.08-3P-BK-S | U1,U2,U6,U7 | CONN-TH_3P-P5.08_DB128L-5.08-3P-BK-S |  | DB128L-5.08-3P-BK-S | DORABO(地博电气) | C430602 | LCSC | T
31 | 1 | ESP32-S3-WROOM-1(N8R8) | U3 | WIRELM-SMD_ESP32-S3-WROOM-1 |  | ESP32-S3-WROOM-1-N8R8 | ESPRESSIF(乐鑫) | C2913201 | LCSC | T
32 | 4 | CYPC817(C-TP2) | U4,U5,U8,U9 | SOP-4_L6.4-W4.6-P2.54-LS10.2-TL |  | CYPC817(C-TP2) | OCIC(卓睿科) | C385058 | LCSC | T
33 | 2 | ZX-PM2.54-2-4PY | U10,U11 | HDR-TH_8P-P2.54-V-F-R2-C4-S2.54 |  | ZX-PM2.54-2-4PY | Megastar(兆星) | C7499340 | LCSC | T
34 | 1 | A2541HWV-7P | U12 | HDR-TH_7P-P2.54-V_A2541HWV-7P |  | A2541HWV-7P | CJT(长江连接器) | C225504 | LCSC | T
35 | 1 | A2541HWV-10P | U13 | HDR-TH_10P-P2.54-V-F-1 |  | A2541HWV-10P | CJT(长江连接器) | C225507 | LCSC | T
36 | 1 | ZX-PM2.54-1-12PY | U14 | HDR-TH_12P-P2.54-V-F |  | ZX-PM2.54-1-12PY | Megastar(兆星) | C7499331 | LCSC | T
37 | 2 | HB-PH3-25414PB2GOP | U15,U16 | HDR-TH_4P-P2.54-V-M |  | HB-PH3-25414PB2GOP | HANBO(汉博) | C6332197 | LCSC | T
38 | 1 | CP2102-GMR | U17 | WQFN-28_L5.0-W5.0-P0.50-BL-EP3.2 |  | CP2102-GMR | SKYWORKS/SILICON LABS(芯科) | C6568 | LCSC | T
39 | 1 | 4.7uF | U18 | C0402 |  | HGC0402R5475K100NTEJ | Chinocera(华瓷) | C7472956 | LCSC | T
40 | 1 | DB128L-5.08-2P-BK-S | U19 | CONN-TH_2P-P5.08_DB128L-5.08-2P-BK-S |  | DB128L-5.08-2P-BK-S | DORABO(地博电气) | C430601 | LCSC | T
41 | 1 | HLK-10M05 | U20 | PWRM-TH_HLK-10M05 |  | HLK-10M05 | HI-LINK(海凌科) | C403745 | LCSC | T
42 | 1 | AMS1117-3.3_C347222 | U21 | SOT-223-4_L6.5-W3.5-P2.30-LS7.0-BR |  | AMS1117-3.3 | UMW(友台半导体) | C347222 | LCSC | T
43 | 1 | LTC4412HVIS6#TRPBF | U22 | TSOT-23-6_L2.9-W1.6-P0.95-LS2.8-BR |  | LTC4412HVIS6#TRPBF | ADI(亚德诺) | C462626 | LCSC | T
44 | 1 | TYPE-C 16PIN 2MD(073) | USB1 | USB-C-SMD_TYPE-C-6PIN-2MD-073 |  | TYPE-C 16PIN 2MD(073) | SHOU HAN(首韩) | C2765186 | LCSC | T

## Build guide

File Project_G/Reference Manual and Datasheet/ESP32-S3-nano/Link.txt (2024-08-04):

https://www.waveshare.com/wiki/ESP32-S3-Nano

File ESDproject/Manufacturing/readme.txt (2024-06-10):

Readme.txt file for the Manufacturing directory.

Student Names: Naren Subburaj
Student Numbers: 8772452
Phone Contact Information: 5483332113
Board Size:6x4 inch

https://can01.safelinks.protection.outlook.com/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

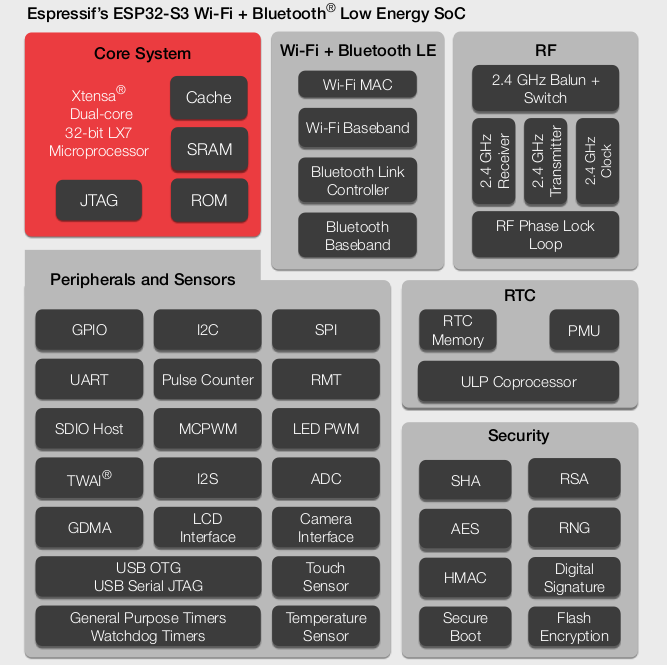
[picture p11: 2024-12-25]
Project_G/Reference Manual and Datasheet/param.png

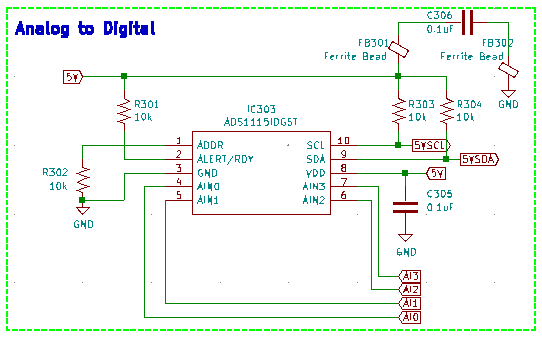
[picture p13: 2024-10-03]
Project_G/Reference Manual and Datasheet/47c38564c9330a93cc9c2ec7061353cf405263bc.png

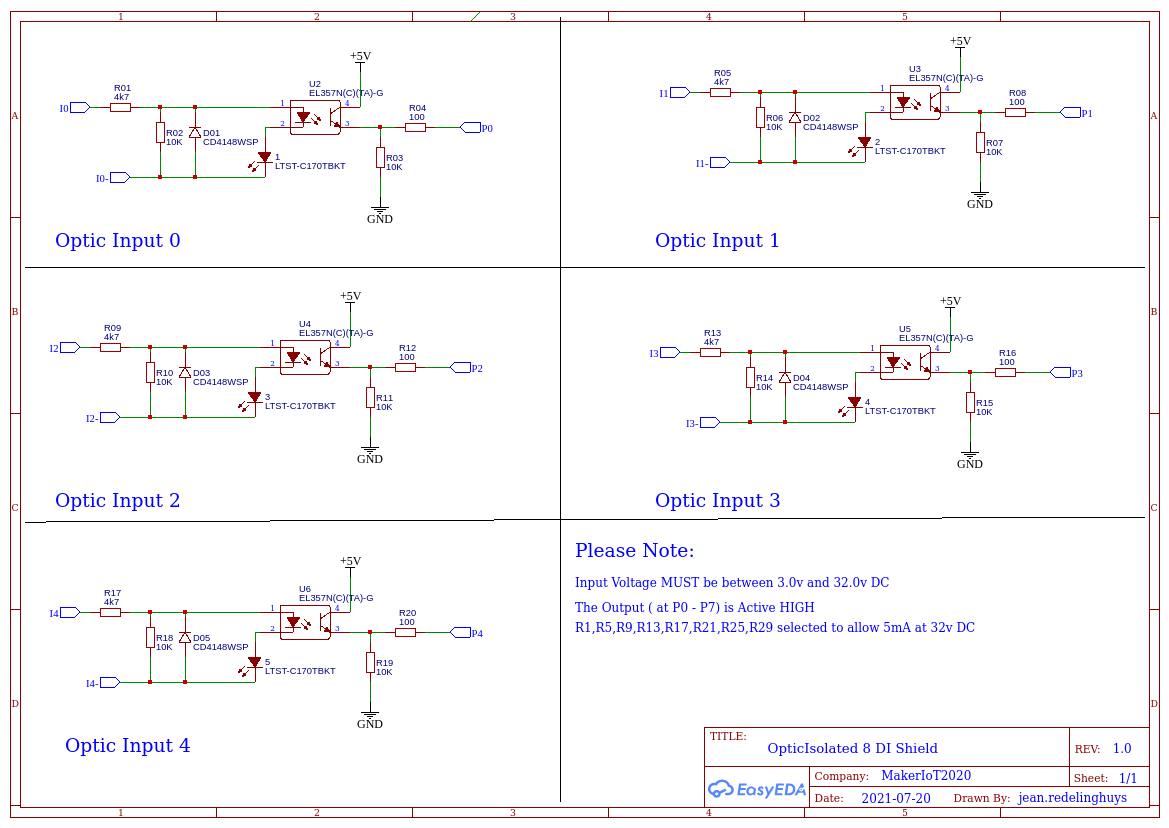
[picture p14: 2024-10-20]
Project_G/Reference Manual and Datasheet/sheet_1_qKF3GgFBAr (Digital-Input).png

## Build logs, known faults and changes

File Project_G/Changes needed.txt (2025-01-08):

Silkscreen update for on/off/auto switch.

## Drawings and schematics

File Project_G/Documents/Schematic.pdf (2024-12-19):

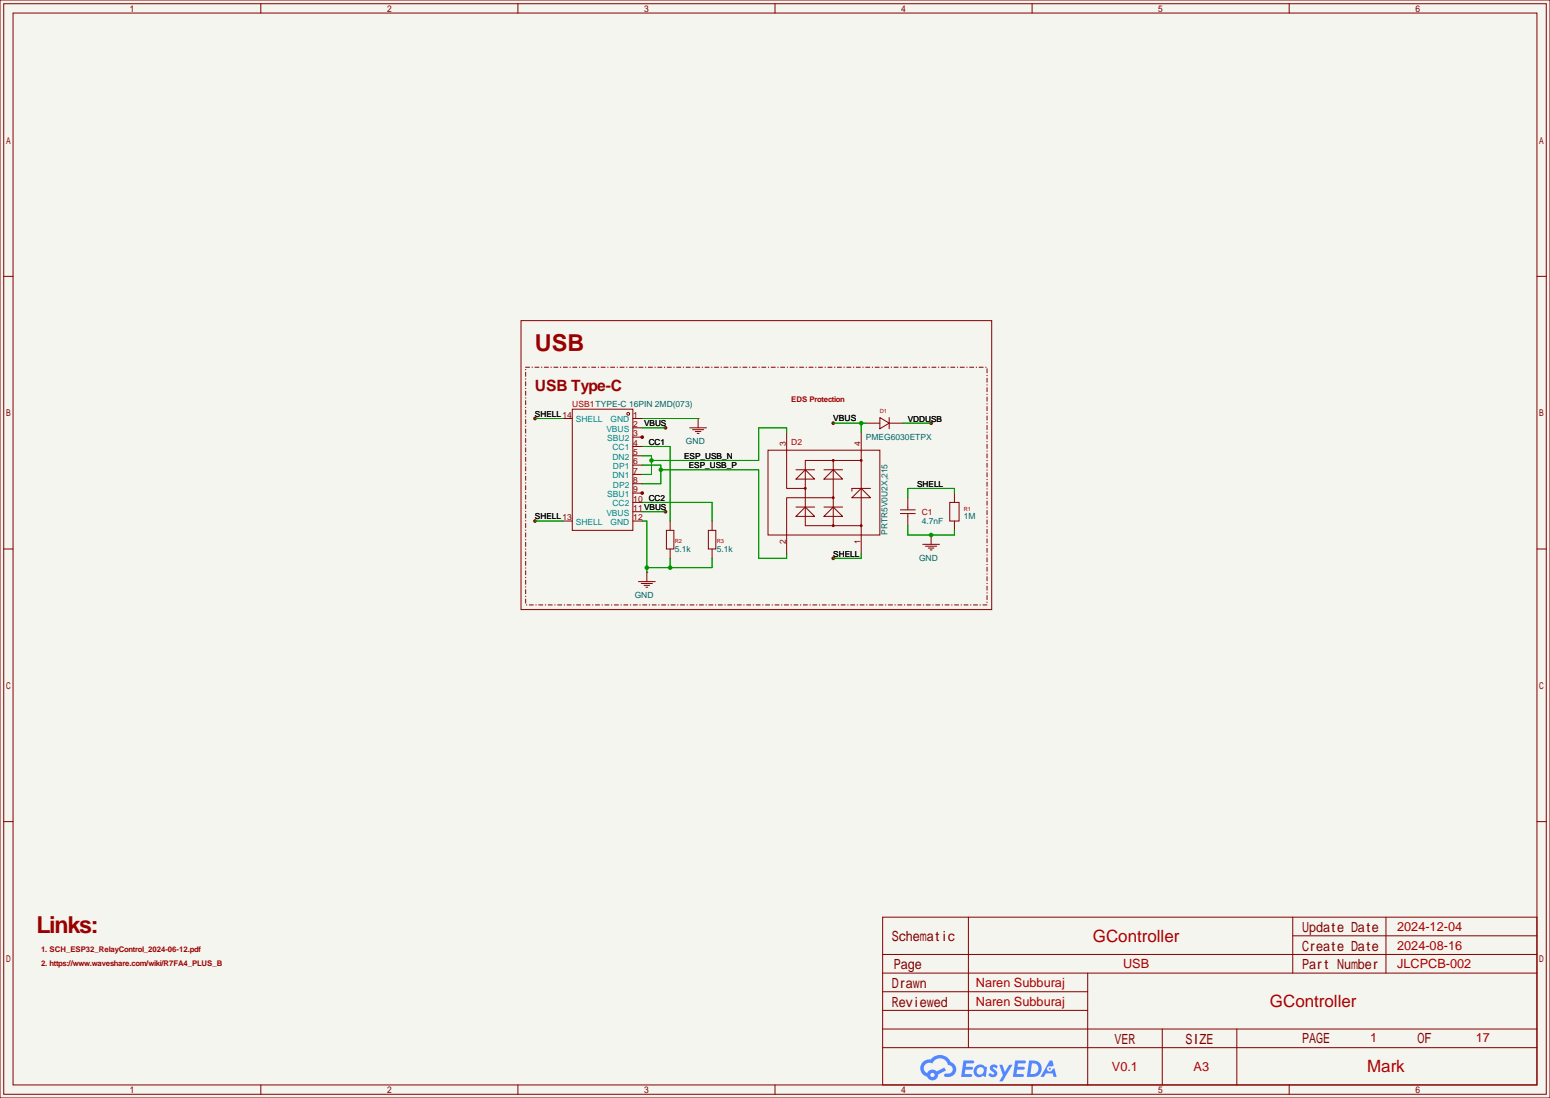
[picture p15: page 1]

1. SCH_ESP32_RelayControl_2024-06-12.pdf
2. https://www.waveshare.com/wiki/R7FA4_PLUS_B

# Buck Convertor

# Input : 15VDC - 36VDC

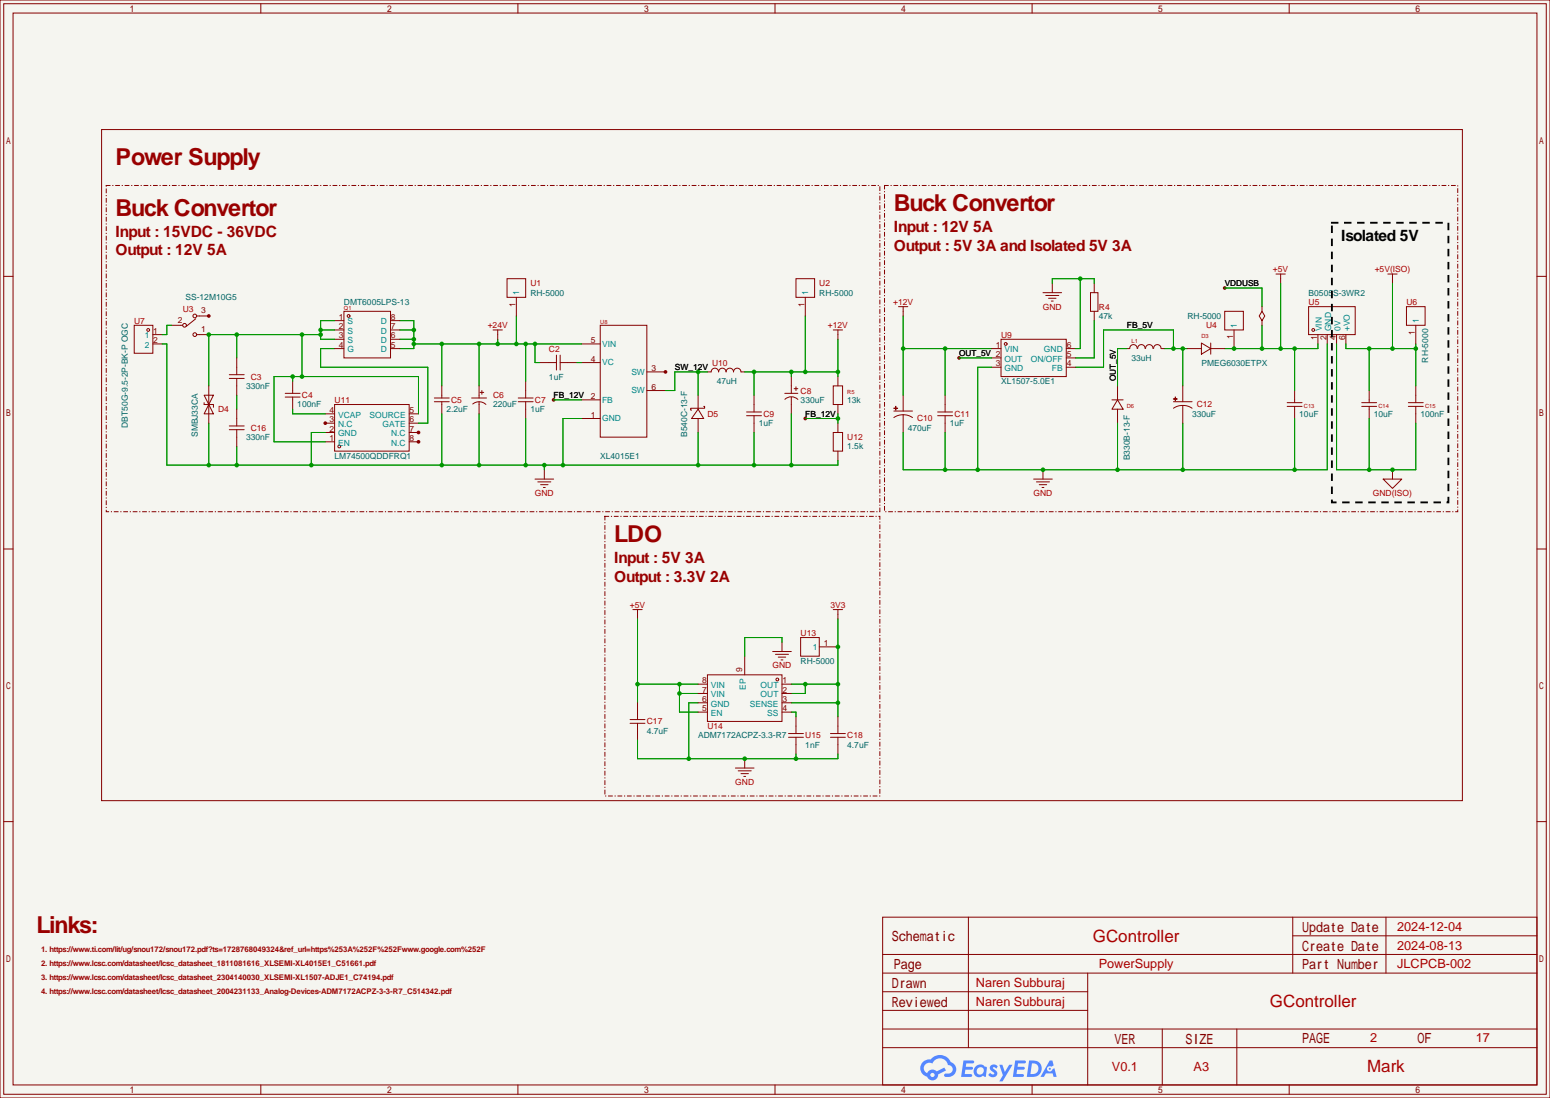
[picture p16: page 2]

1. https://www.ti.com/lit/ug/snou172/snou172.pdf?ts=1728768049324&ref_url=https%253A%252F%252Fwww.google.com%252F
2. https://www.lcsc.com/datasheet/lcsc_datasheet_1811081616_XLSEMI-XL4015E1_C51661.pdf
3. https://www.lcsc.com/datasheet/lcsc_datasheet_2304140030_XLSEMI-XL1507-ADJE1_C74194.pdf
4. https://www.lcsc.com/datasheet/lcsc_datasheet_2004231133_Analog-Devices-ADM7172ACPZ-3-3-R7_C514342.pdf

# Touch Power Supply

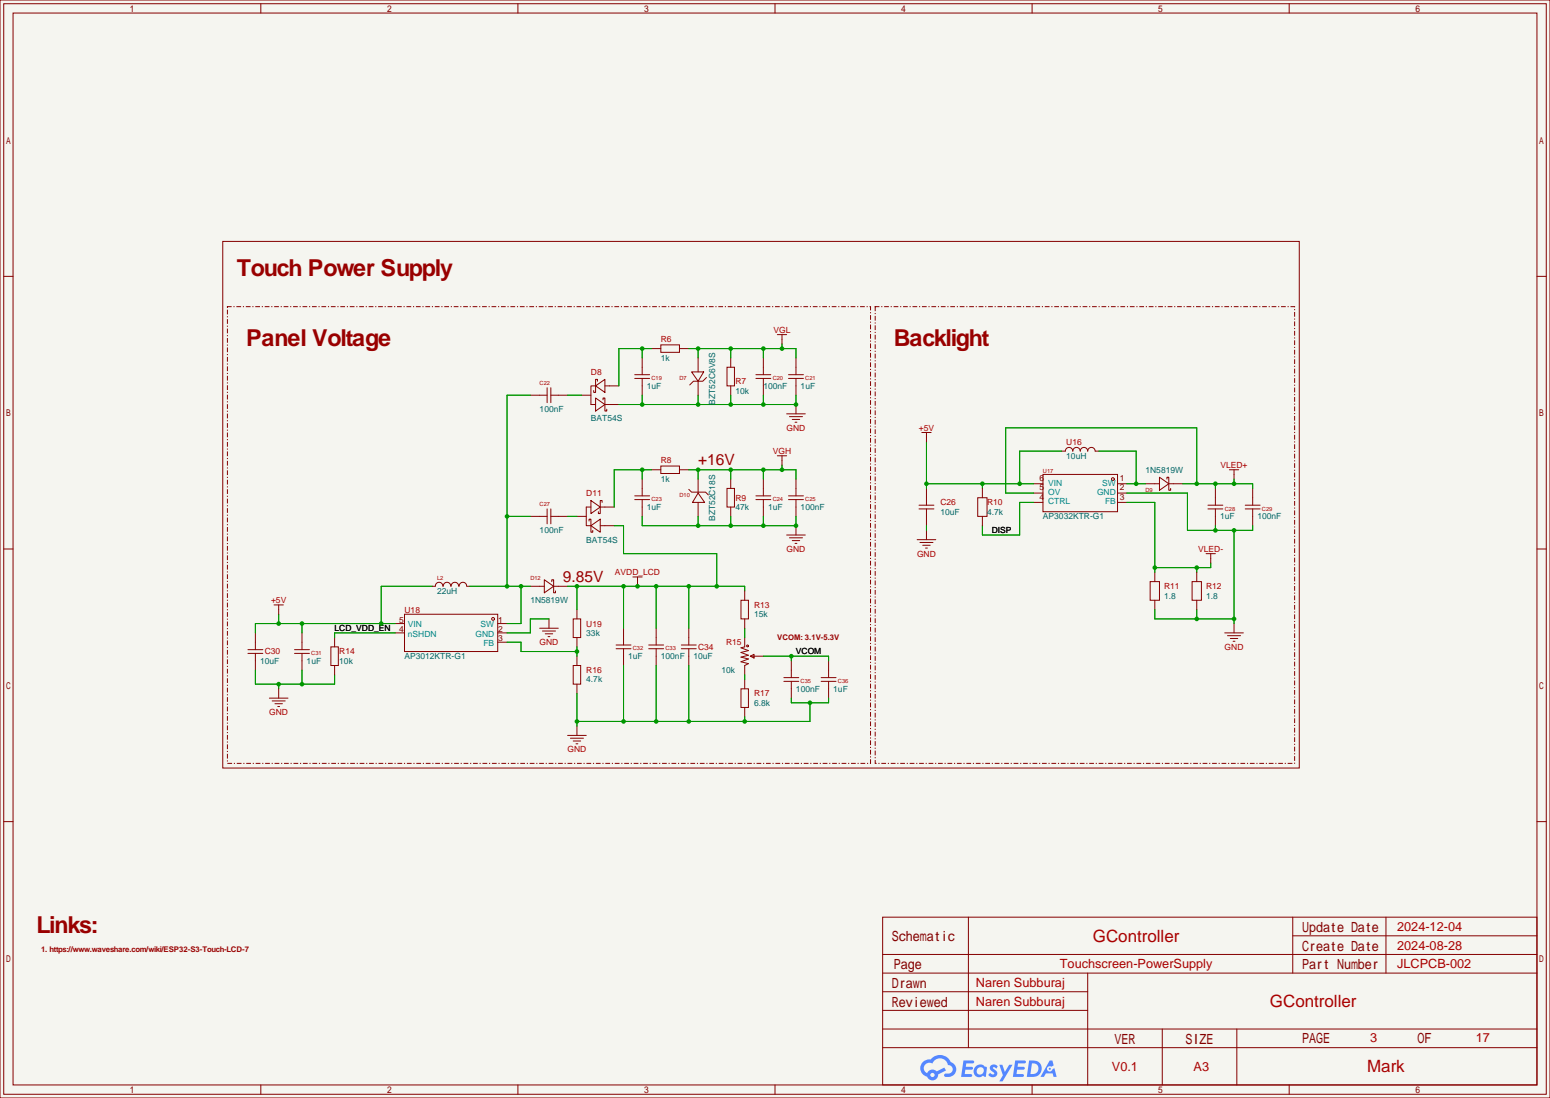
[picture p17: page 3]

1. https://www.waveshare.com/wiki/ESP32-S3-Touch-LCD-7

# ESP32

# FPC Connector

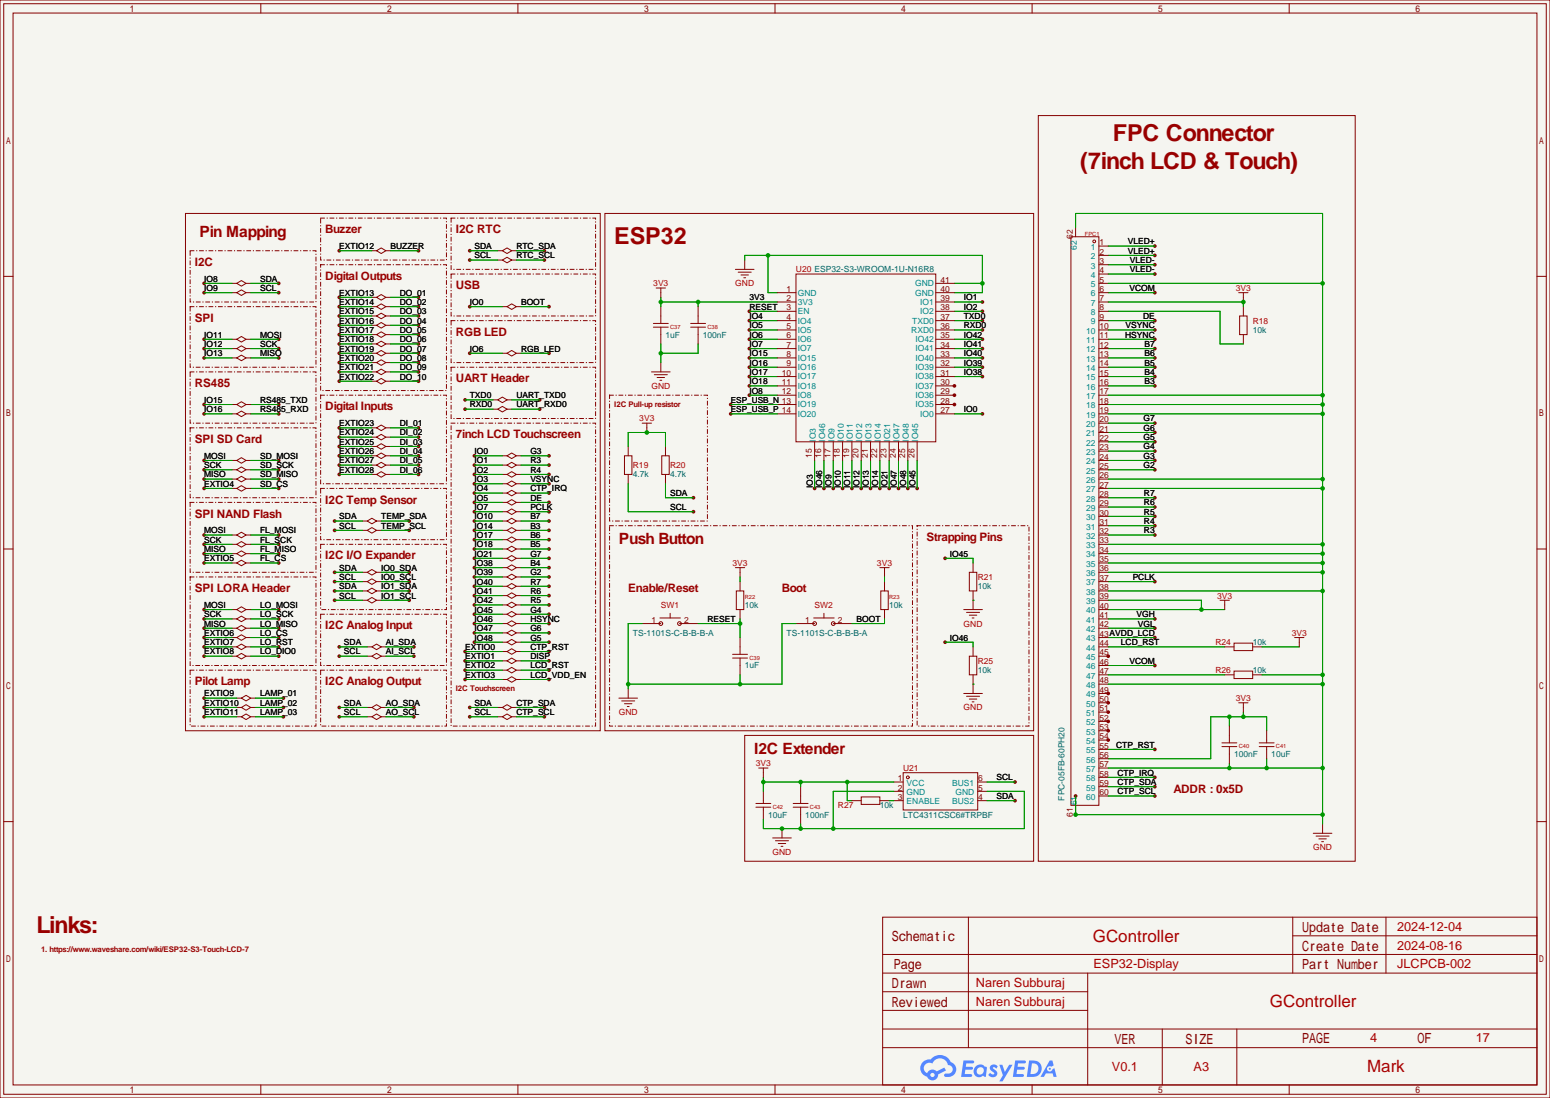
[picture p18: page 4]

1. https://www.waveshare.com/wiki/ESP32-S3-Touch-LCD-7

# I/O Expander

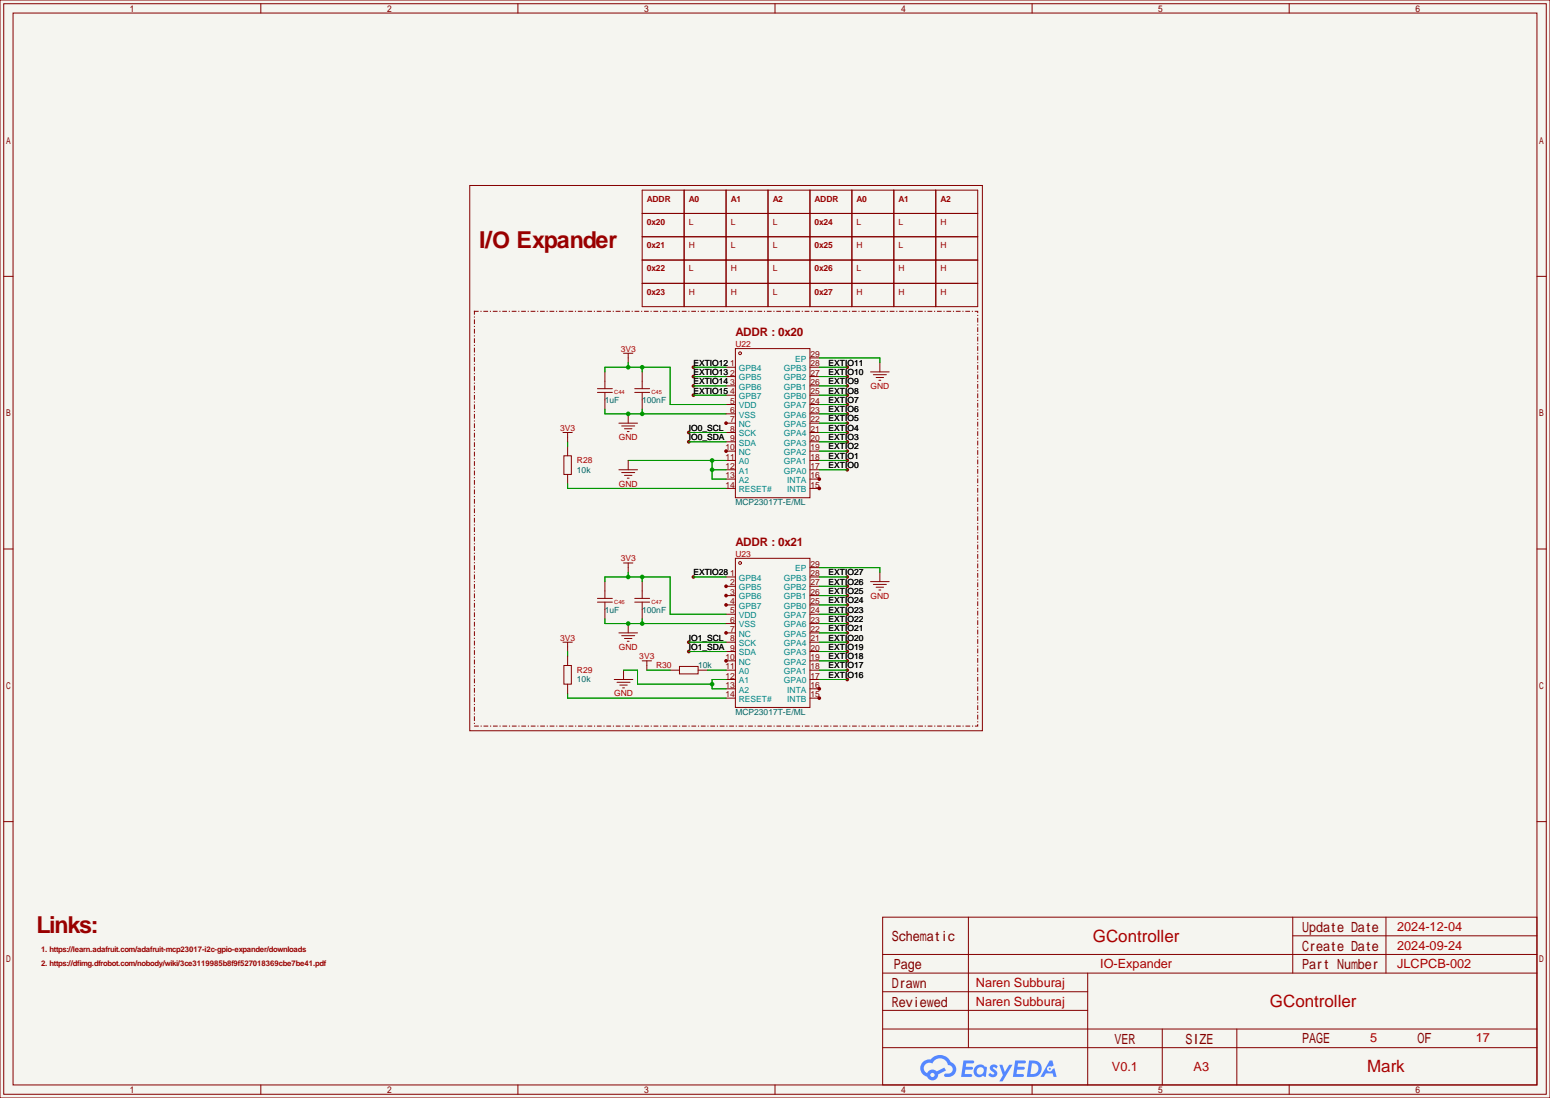
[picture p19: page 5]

ADDR | A0 | A1 | A2 | ADDR | A0 | A1 | A2

1. https://learn.adafruit.com/adafruit-mcp23017-i2c-gpio-expander/downloads
2. https://dfimg.dfrobot.com/nobody/wiki/3ce3119985b8f9f527018369cbe7be41.pdf

## D13LL4148

Inverter | Digital/Power isolater

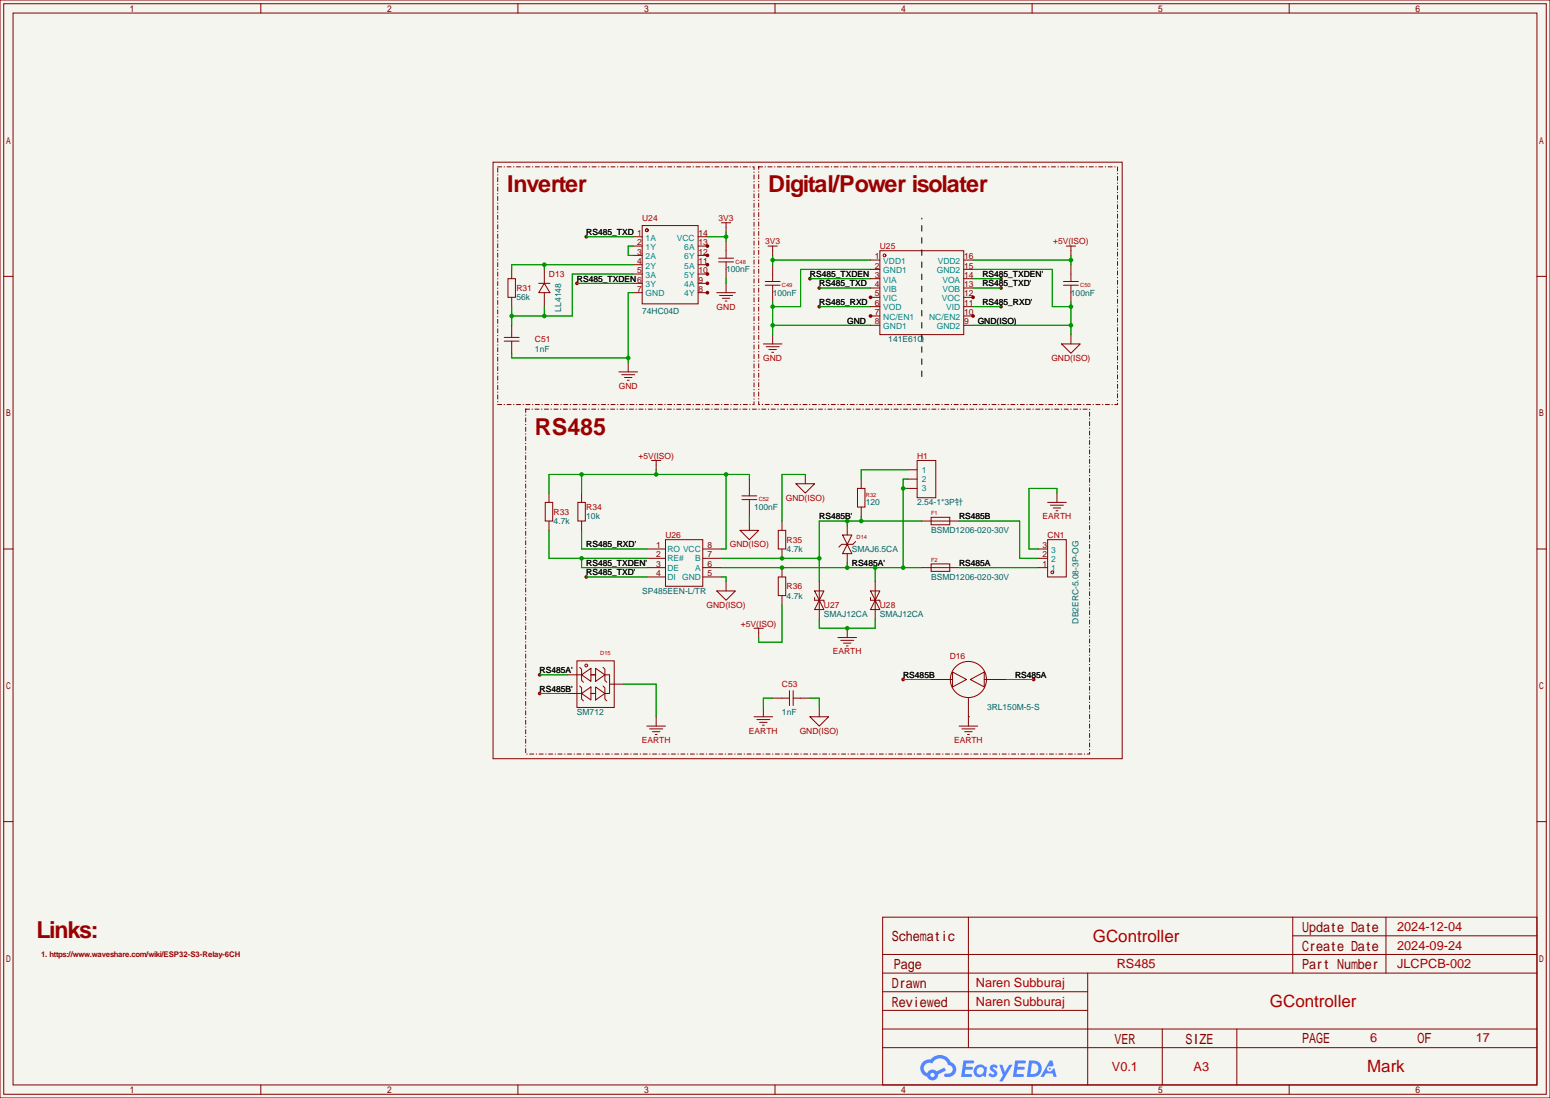
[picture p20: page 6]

NC/EN2 10 VID 11 VOC 12 VOB 13 VOA 14 GND2 15 VDD2 16

1. https://www.waveshare.com/wiki/ESP32-S3-Relay-6CH

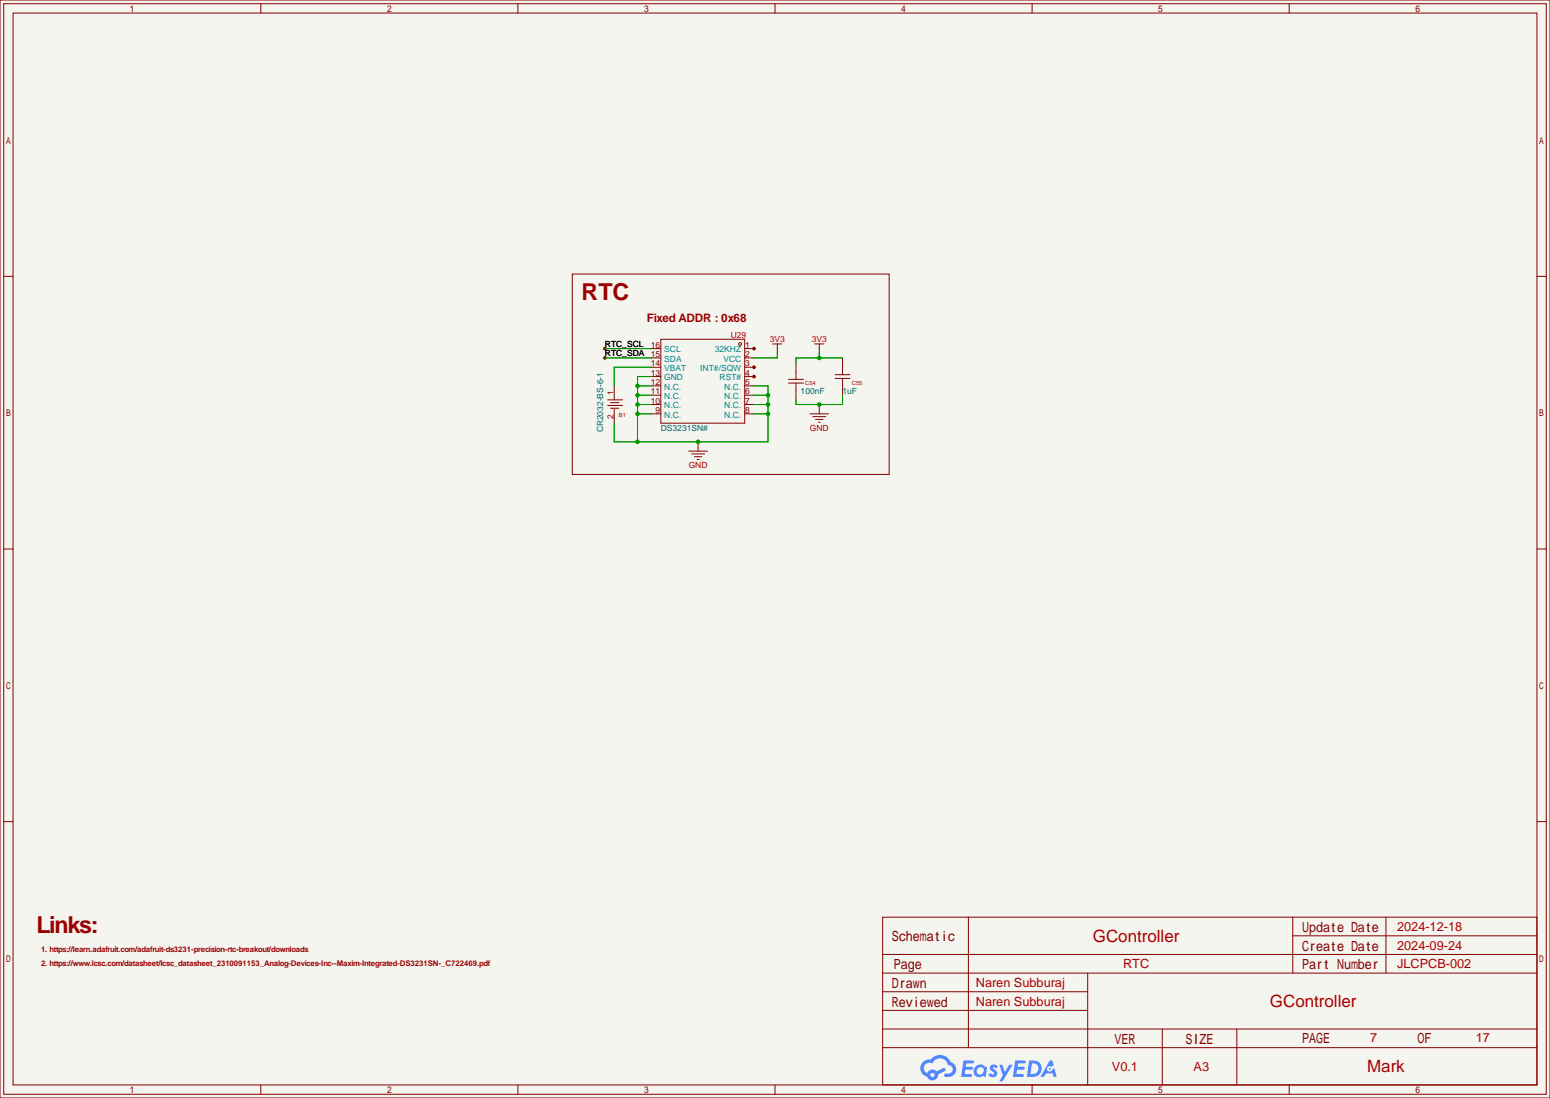
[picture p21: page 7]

1. https://learn.adafruit.com/adafruit-ds3231-precision-rtc-breakout/downloads
2. https://www.lcsc.com/datasheet/lcsc_datasheet_2310091153_Analog-Devices-Inc--Maxim-Integrated-DS3231SN-_C722469.pdf

# Storage

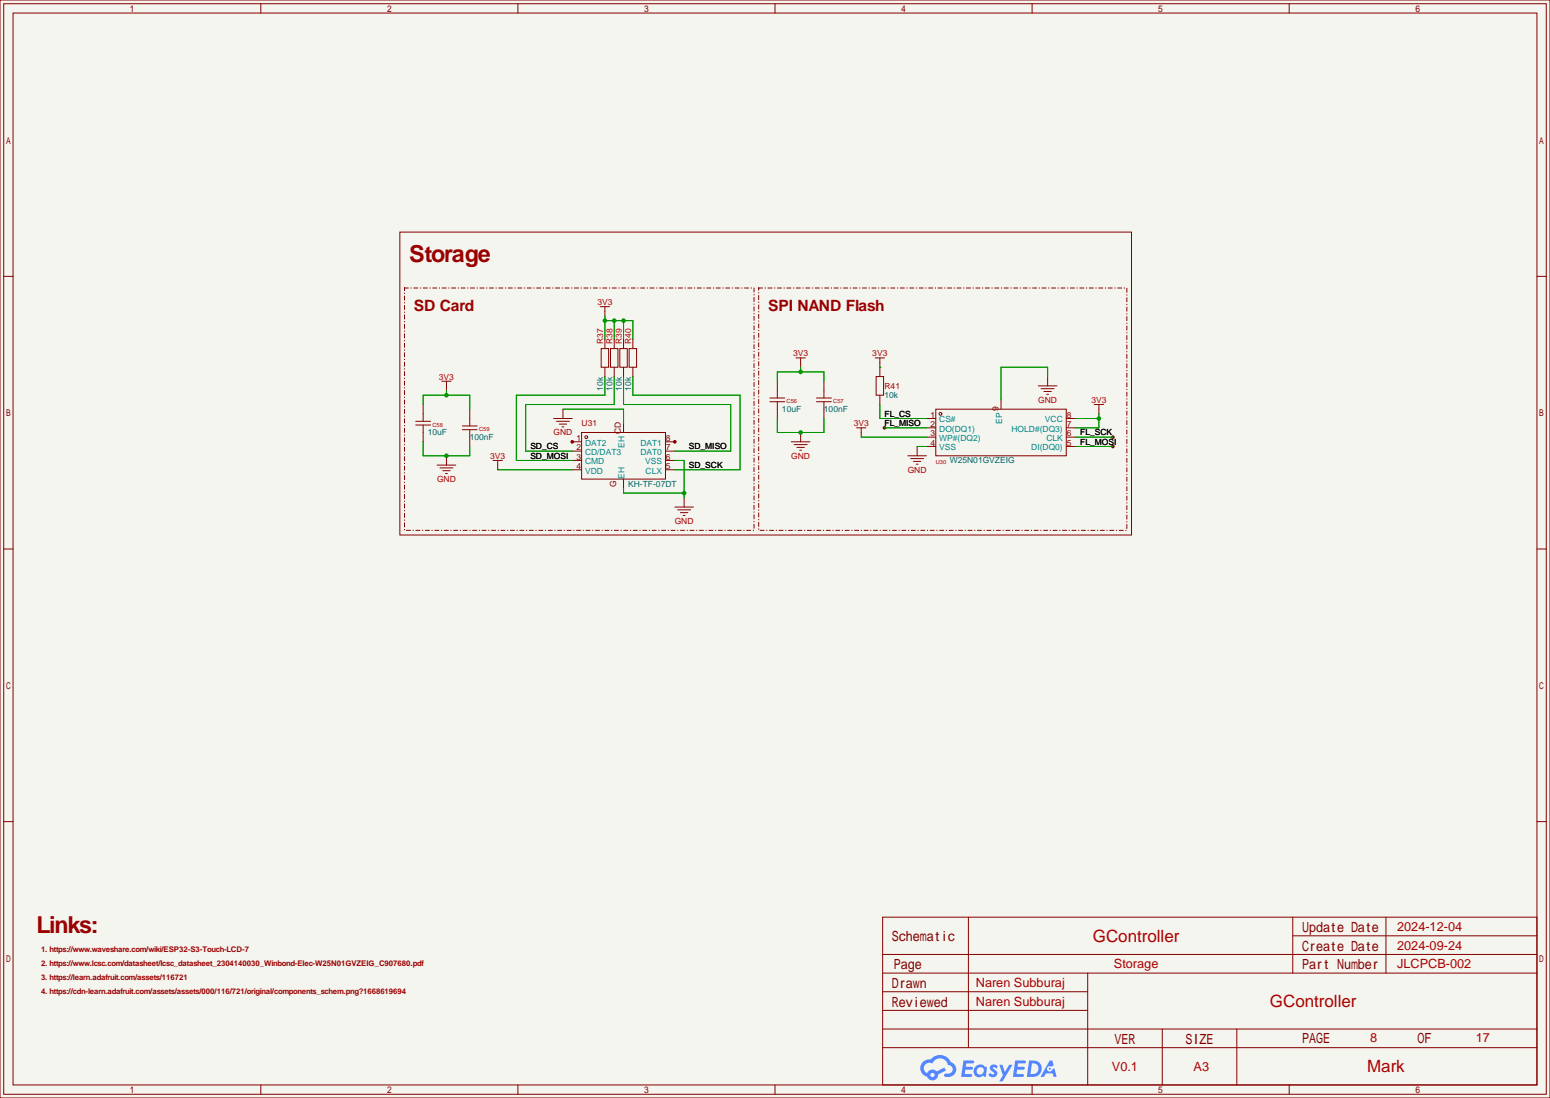
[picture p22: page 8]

1. https://www.waveshare.com/wiki/ESP32-S3-Touch-LCD-7
2. https://www.lcsc.com/datasheet/lcsc_datasheet_2304140030_Winbond-Elec-W25N01GVZEIG_C907680.pdf
3. https://learn.adafruit.com/assets/116721
4. https://cdn-learn.adafruit.com/assets/assets/000/116/721/original/components_schem.png?1668619694

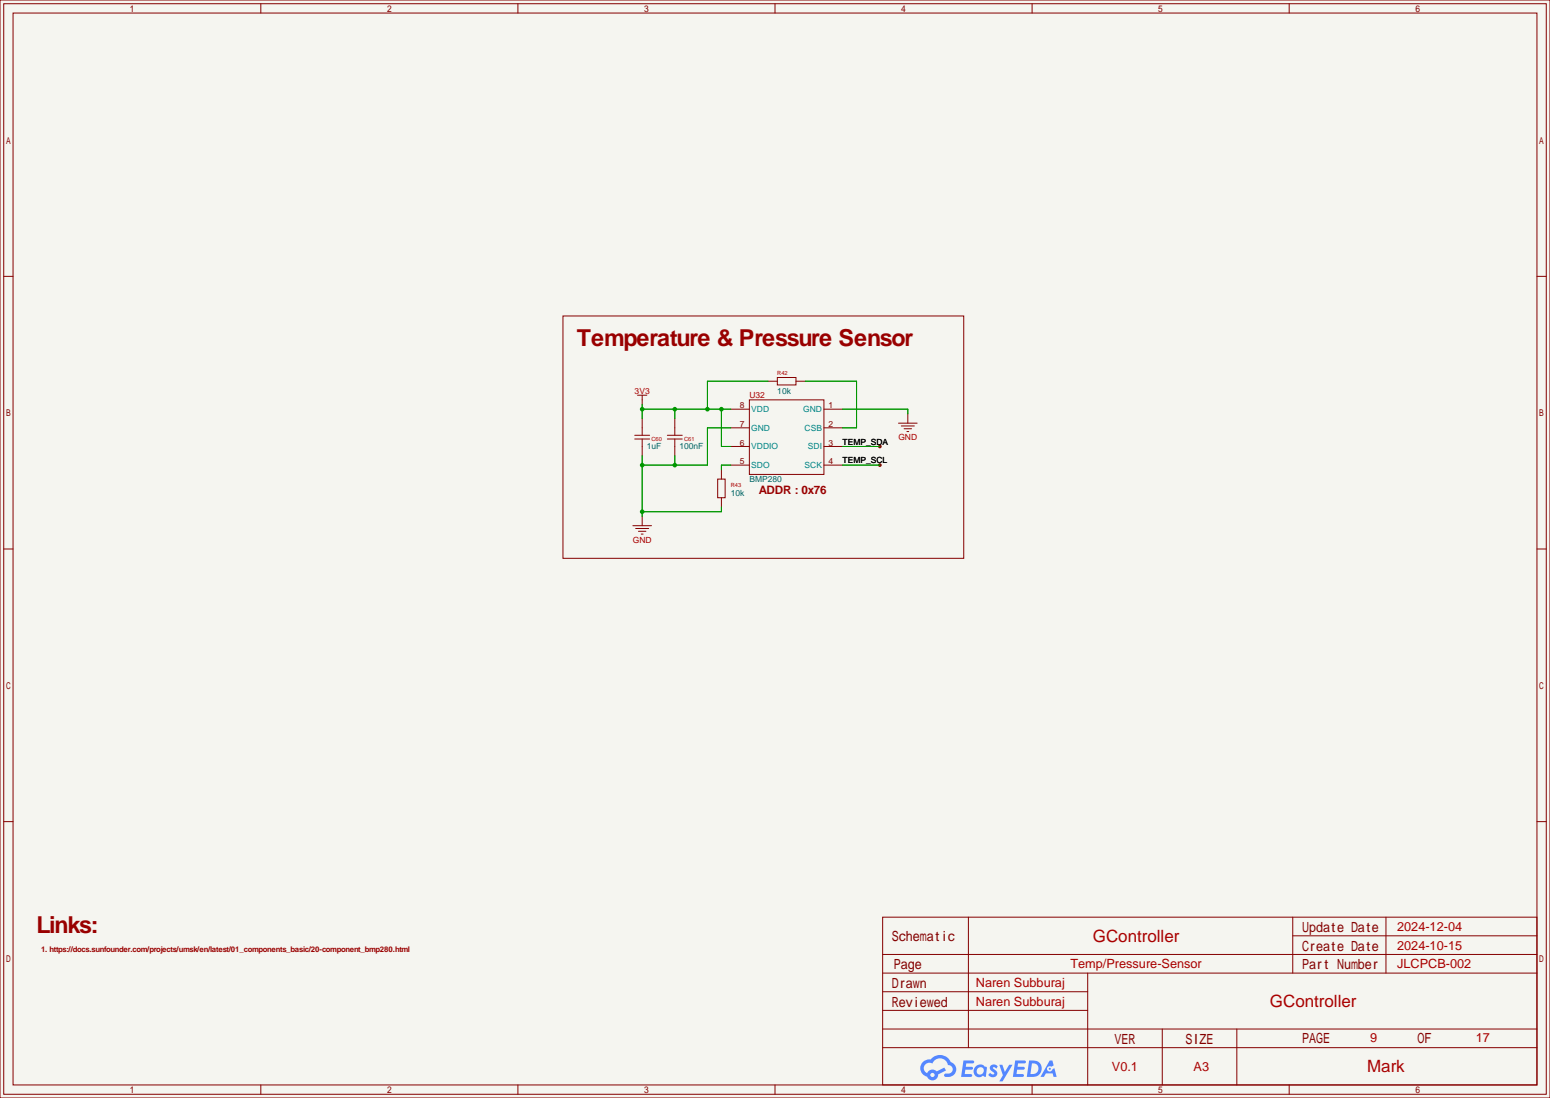
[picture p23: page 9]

1. https://docs.sunfounder.com/projects/umsk/en/latest/01_components_basic/20-component_bmp280.html

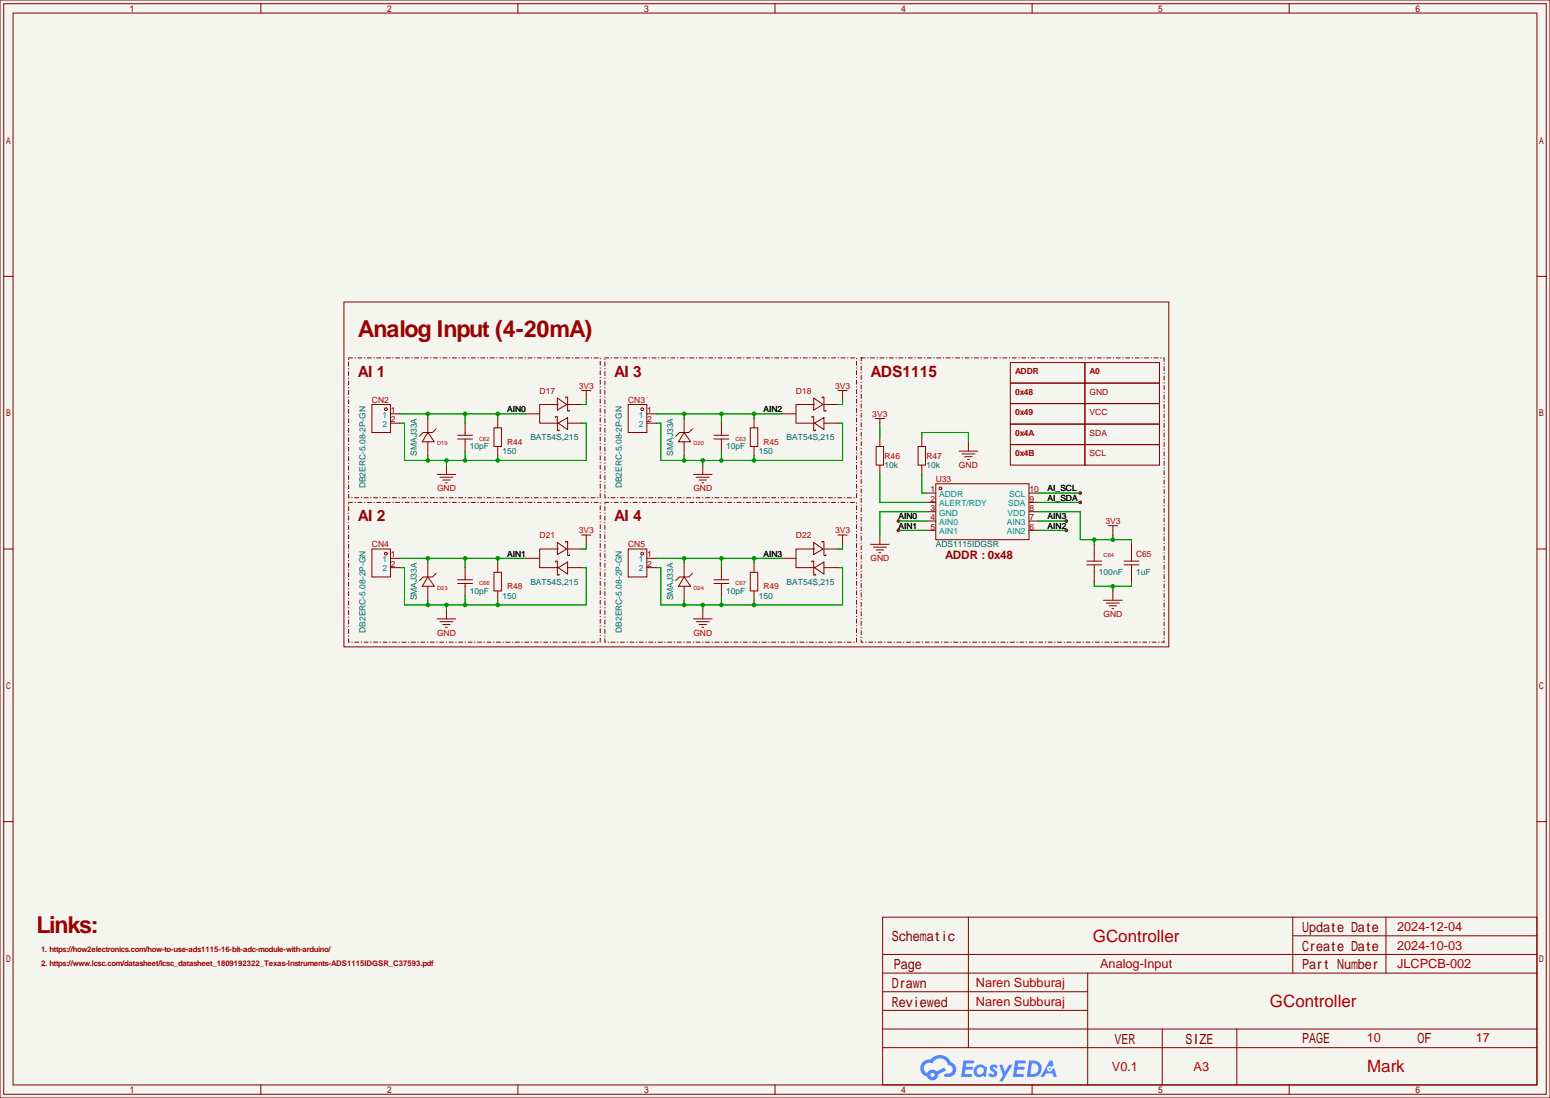
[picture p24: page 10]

ADDR | A0
0x48 | GND
0x49 | VCC
0x4A | SDA
0x4B | SCL

1. https://how2electronics.com/how-to-use-ads1115-16-bit-adc-module-with-arduino/
2. https://www.lcsc.com/datasheet/lcsc_datasheet_1809192322_Texas-Instruments-ADS1115IDGSR_C37593.pdf

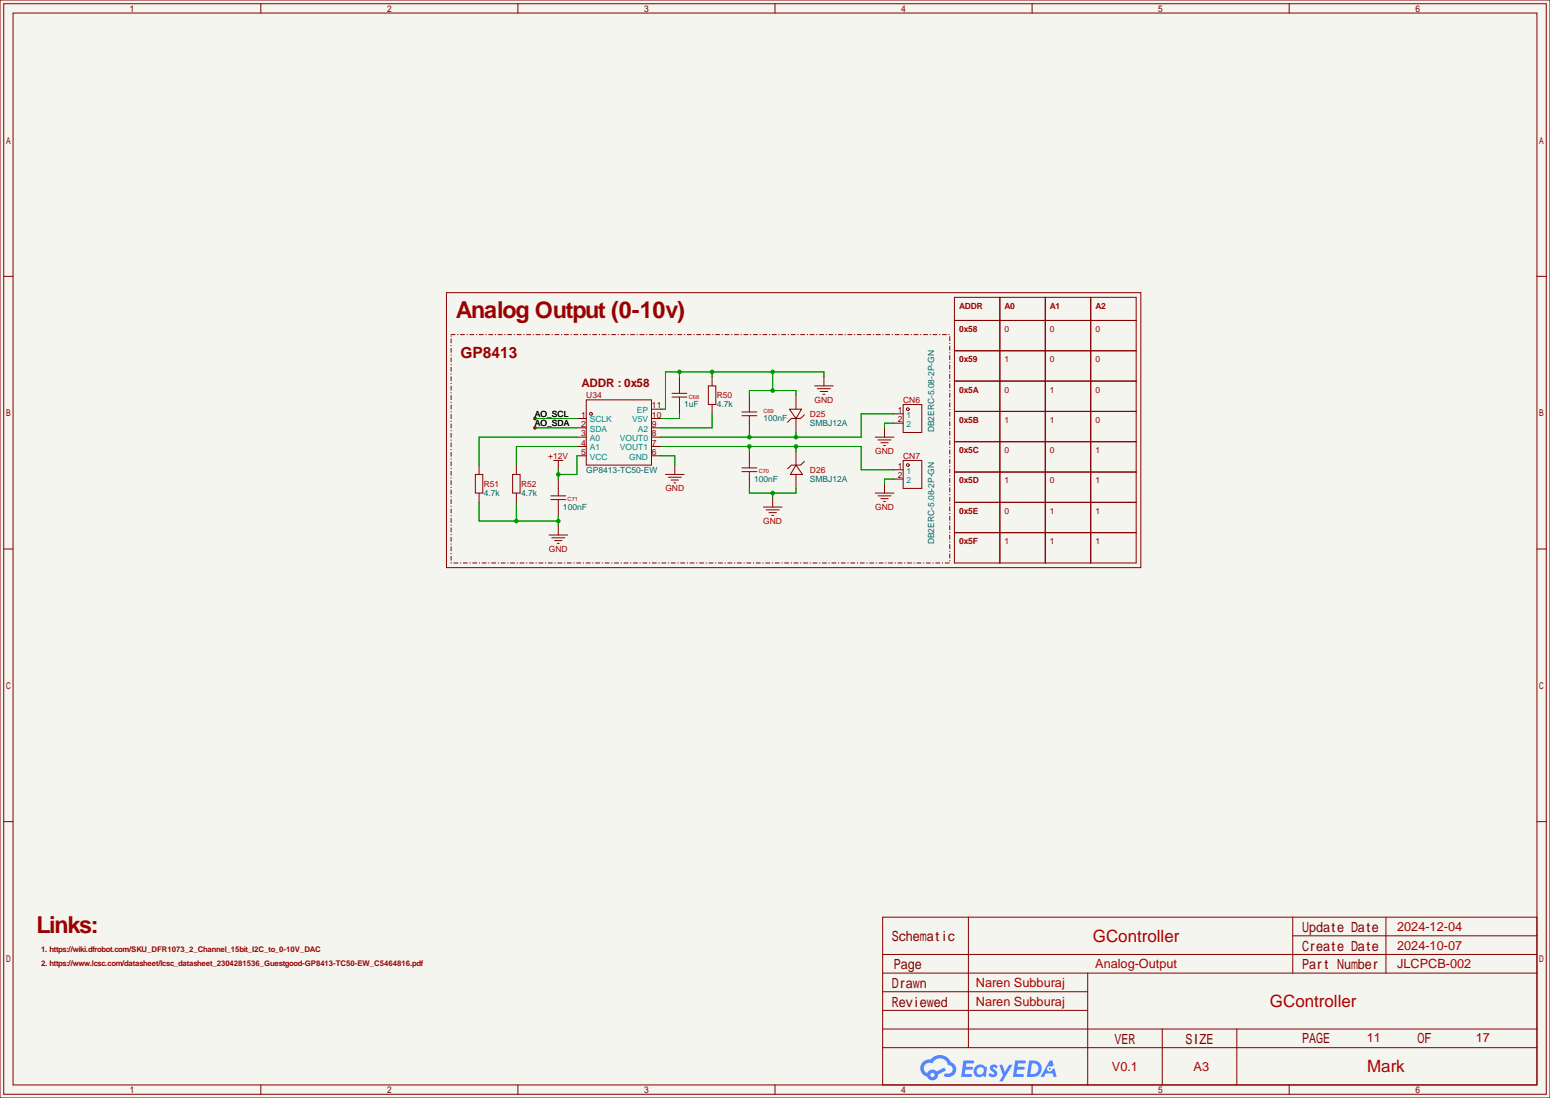
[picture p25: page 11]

ADDR | A0 | A1 | A2

1. https://wiki.dfrobot.com/SKU_DFR1073_2_Channel_15bit_I2C_to_0-10V_DAC
2. https://www.lcsc.com/datasheet/lcsc_datasheet_2304281536_Guestgood-GP8413-TC50-EW_C5464816.pdf

# Digital Input (3 - 32VDC@5mA)

DI 1

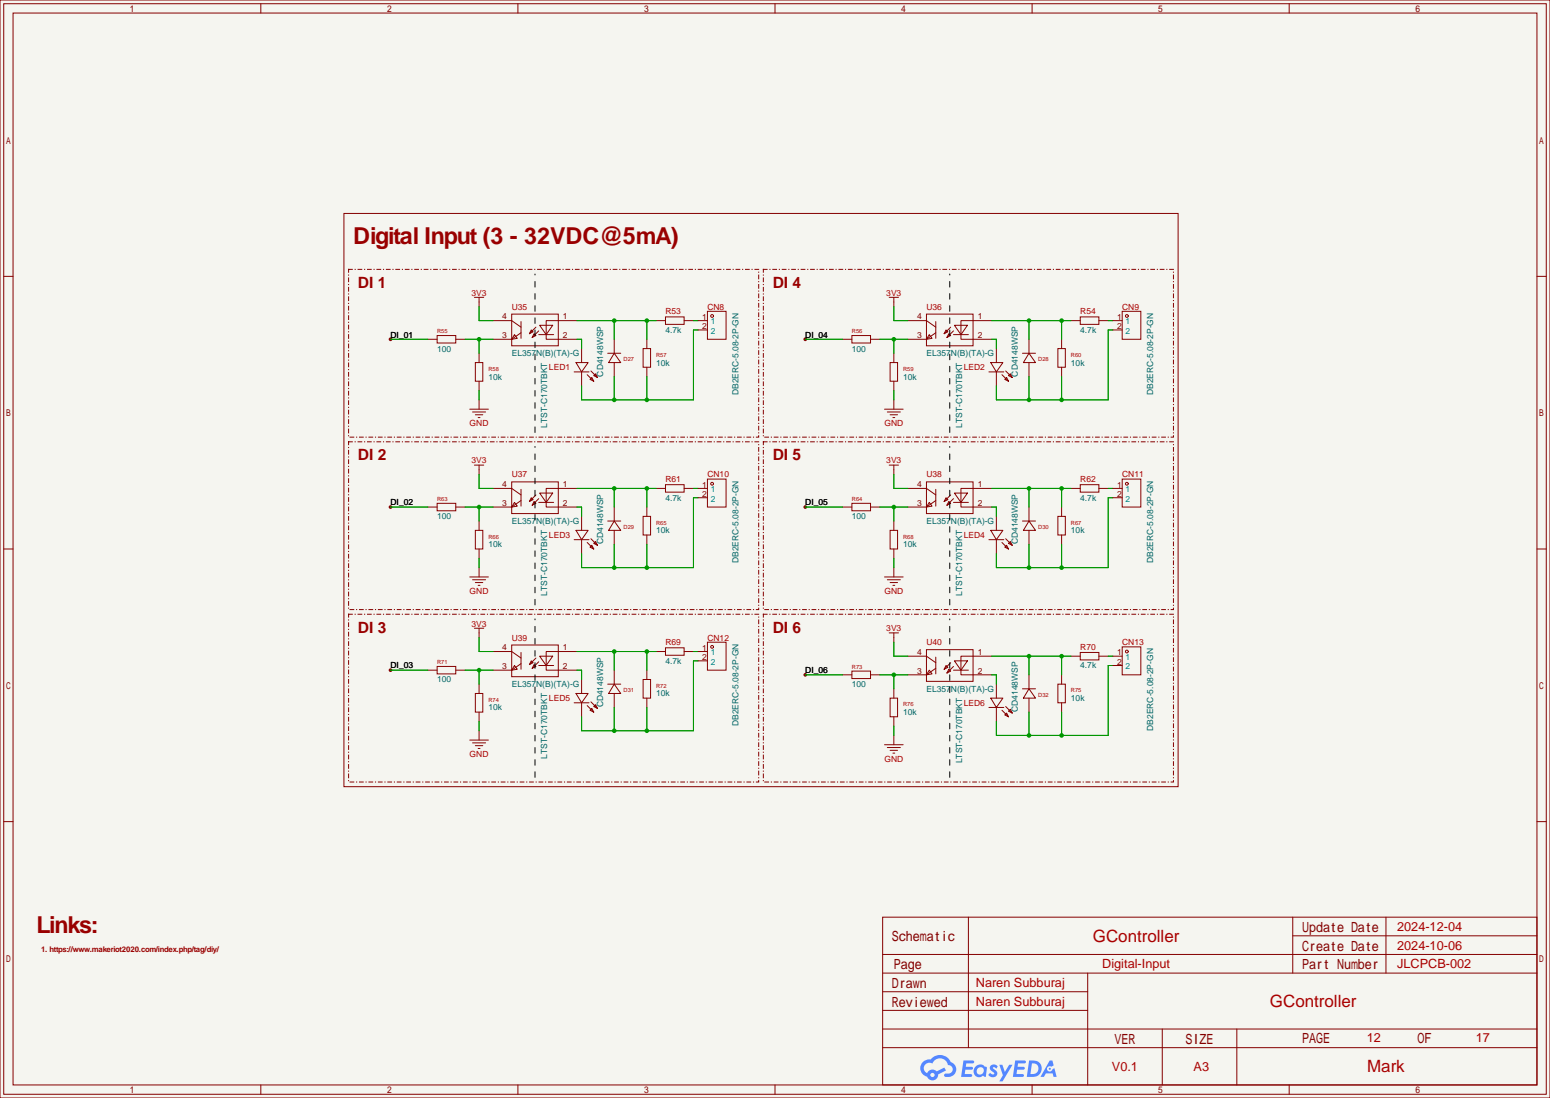
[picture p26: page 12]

1. https://www.makeriot2020.com/index.php/tag/diy/

DO 1 | DO 2 | DO 3

# Digital Output - MOSFET


GND
Digital Output Power Supply

1. https://robojax.com/learn/arduino/?vid=robojax_e-switch_IRF5305
2. https://www.waveshare.com/wiki/ESP32-S3-Relay-6CH


1. https://www.waveshare.com/wiki/ESP32-S3-Relay-6CH


# LAMP 1

# Pilot Lamp


(Running, Alarm and Stopped)


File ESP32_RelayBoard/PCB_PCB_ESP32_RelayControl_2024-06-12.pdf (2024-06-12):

## RELAY1 - GPIO4

## RELAY2 - GPIO5




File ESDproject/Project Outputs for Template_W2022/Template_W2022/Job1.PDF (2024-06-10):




USB TO TTL UART INTERFACE

U1
GND 1

NOTE: TX and RX connections

VD+ 5
VD- 6

MOTOR1_ENCODER_A

AS-12.000-18-SMD-TR

i Power

GND 17 GND 16 GND 15 GND 14

Power i

Title
Display, Analog, DC Motors, USB to UART


1 8 | 9 | i
1 7


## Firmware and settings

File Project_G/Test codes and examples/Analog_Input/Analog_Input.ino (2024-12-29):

#include <Wire.h>
#include <Adafruit_ADS1X15.h>

// Create an object for the ADS1115 sensor
Adafruit_ADS1115 ads;

// Define SDA and SCL pins
#define SDA_PIN 8
#define SCL_PIN 9

// Channel pins for ADS1115 (default channels 0, 1, 2, 3)
#define CHANNEL_0 0  // Temperature
#define CHANNEL_1 1  // Humidity
#define CHANNEL_2 2
#define CHANNEL_3 3

// Define the ADS multiplier (used to adjust the voltage calculation)
#define ADS_MULTIPLIER 1.86623

// Define the resistance for the 4-20 mA current loop (150 ohms)
#define RESISTOR 150.0

// Temperature (Channel 0) range (-20°C to 80°C)
#define TEMP_MIN -20
#define TEMP_MAX 80

// Humidity (Channel 1) range (0% to 100%)
#define HUM_MIN 0
#define HUM_MAX 100

// Calculate the voltage range for the 4-20 mA current loop across the 150-ohm resistor
// Using Ohm's Law: V = I * R
// For 4 mA (min current) -> V = 0.004 A * 150 ohms = 0.6 V
// For 20 mA (max current) -> V = 0.02 A * 150 ohms = 3.0 V
#define VOLTAGE_MIN 0.6                            // Corresponding to 4mA
#define VOLTAGE_MAX 3.0                            // Corresponding to 20mA
#define VOLTAGE_RANGE (VOLTAGE_MAX - VOLTAGE_MIN)  // This is 2.4V (3.0V - 0.6V)

// Calculate the scaling factor for converting voltage to the desired range (Temperature or Humidity)
#define VOLTAGE_SCALE (VOLTAGE_RANGE)  // 2.4V range for 4-20mA

void setup() {
  // Initialize Serial communication
  Serial.begin(115200);
  while (!Serial) {
    delay(10);  // Wait for Serial Monitor to be ready
  }

  // Initialize I2C communication
  Wire.begin(SDA_PIN, SCL_PIN);

  // Initialize the ADS1115
  if (!ads.begin()) {
    Serial.println("Couldn't find ADS1115!");
    while (1)
      ;  // Halt the program if the sensor is not found
  }

  Serial.println("ADS1115 sensor found!");
}

void loop() {
  // Read and process each channel
  for (int channel = CHANNEL_0; channel <= CHANNEL_3; channel++) {
    // Read analog values from the selected channel
    int16_t raw_value = ads.readADC_SingleEnded(channel);  // Read from the channel

    // Convert raw value to voltage using the ADS multiplier
    float voltage = raw_value * (3.3 * ADS_MULTIPLIER) / 32768.0;  // Corrected voltage calculation

    // For Channels 0 (Temperature) and 1 (Humidity), map voltage to the respective range
    if (channel == CHANNEL_0) {
      // Calculate temperature for Channel 0 (Temperature range: -20°C to 80°C)
      float temperature = map_voltage_to_temperature(voltage);
      Serial.print("Channel 0 (Temperature) - Voltage: ");
      Serial.print(voltage, 4);
      Serial.print(" V  Temperature: ");
      Serial.print(temperature);
      Serial.println(" °C");
    } else if (channel == CHANNEL_1) {
      // Calculate humidity for Channel 1 (Humidity range: 0% to 100%)
      float humidity = map_voltage_to_humidity(voltage);
      Serial.print("Channel 1 (Humidity) - Voltage: ");
      Serial.print(voltage, 4);
      Serial.print(" V  Humidity: ");
      Serial.print(humidity);
      Serial.println(" %");
    } else {
      // For other channels, just print the voltage
      Serial.print("Channel ");
      Serial.print(channel);
      Serial.print(" - Voltage: ");
      Serial.print(voltage, 4);
      Serial.println(" V");
    }
  }

  // Wait for a second before reading again
  delay(1000);
}

// Refined map for temperature based on voltage (0.4V to 2.0V -> -20°C to 80°C)
float map_voltage_to_temperature(float voltage) {
  // Map voltage to temperature range (-20°C to 80°C)
  float temperature = (voltage - VOLTAGE_MIN) * (TEMP_MAX - TEMP_MIN) / VOLTAGE_RANGE + TEMP_MIN;
  return temperature;
}

// Map the voltage (4-20 mA range) to humidity (0% to 100%) for Channel 1
float map_voltage_to_humidity(float voltage) {
  // Map voltage to humidity range (0% to 100%)
  float humidity = (voltage - VOLTAGE_MIN) * (HUM_MAX - HUM_MIN) / VOLTAGE_RANGE + HUM_MIN;
  return humidity;
}

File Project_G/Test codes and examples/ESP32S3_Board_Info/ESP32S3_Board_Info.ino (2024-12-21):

#include <WiFi.h>
#include <esp_system.h>
#include <esp_wifi.h>
#include <esp_mac.h>

void setup() {
  // Initialize Serial
  Serial.begin(115200);
  while (!Serial) {
    delay(10); // Wait for the Serial connection
  }

  Serial.println("\n--- ESP32-S3 Board Information ---");

  // Chip Information
  Serial.println("\nChip Information:");
  Serial.printf("  Model: %s\n", ESP.getChipModel());
  Serial.printf("  Cores: %d\n", ESP.getChipCores());
  Serial.printf("  Revision: %d\n", ESP.getChipRevision());
  Serial.printf("  CPU Frequency: %d MHz\n", ESP.getCpuFreqMHz());
  Serial.printf("  Flash Size: %dMB\n", ESP.getFlashChipSize() / (1024 * 1024));
  Serial.printf("  Flash Speed: %d MHz\n", ESP.getFlashChipSpeed() / 1000000);
  Serial.printf("  Flash Mode: %s\n", (ESP.getFlashChipMode() == FM_QIO) ? "QIO" : 
                                     (ESP.getFlashChipMode() == FM_QOUT) ? "QOUT" :
                                     (ESP.getFlashChipMode() == FM_DIO) ? "DIO" : 
                                     "DOUT");

  // PSRAM Information
  Serial.println("\nPSRAM Information:");
  Serial.printf("  PSRAM: %s\n", (ESP.getPsramSize() > 0) ? "Available" : "Not Available");
  if (ESP.getPsramSize() > 0) {
    Serial.printf("  PSRAM Size: %dMB\n", ESP.getPsramSize() / (1024 * 1024));
  }

  // MAC Address
  Serial.println("\nMAC Address:");
  String mac = WiFi.macAddress();
  Serial.printf("  MAC Address: %s\n", mac.c_str());

  // Chip Unique ID (using EFuse MAC Address)
  uint64_t chip_id = ESP.getEfuseMac();
  Serial.printf("\nChip Unique ID (EFuse MAC): %llx\n", chip_id);

  // Free Heap
  Serial.println("\nMemory Information:");
  Serial.printf("  Free Heap: %d bytes\n", ESP.getFreeHeap());

  // Flash Information
  Serial.printf("  Flash Size: %d bytes\n", ESP.getFlashChipSize());
  Serial.printf("  Free Flash: %d bytes\n", ESP.getFreeSketchSpace());

  // System Info
  Serial.println("\nSystem Information:");
  Serial.printf("  SDK Version: %s\n", esp_get_idf_version()); // Fixed for version string
  
  // Reset Reason and Boot Mode Inference
  Serial.printf("  Reset Reason: %d\n", esp_reset_reason());
  if (esp_reset_reason() == ESP_RST_POWERON) {
    Serial.println("  Boot Mode: Power-On Reset");
  } else if (esp_reset_reason() == ESP_RST_BROWNOUT) {
    Serial.println("  Boot Mode: Brownout Reset");
  } else if (esp_reset_reason() == ESP_RST_SDIO) {
    Serial.println("  Boot Mode: SDIO Reset");
  } else {
    Serial.println("  Boot Mode: Unknown Reset");
  }

  // Flash Encryption Status
  // You can check encryption with other methods depending on the SDK/platform you're using
  // Example (if configured in your ESP32 project):
  // bool flash_encryption = esp_flash_encryption_enabled();
  Serial.printf("  Flash Encryption: %s\n", "Disabled"); // Placeholder, as this method is unavailable directly

  // Other Debugging Info
  Serial.println("\nOther Information:");
  Serial.printf("  Sketch Size: %d bytes\n", ESP.getSketchSize());
  Serial.printf("  Free Sketch Space: %d bytes\n", ESP.getFreeSketchSpace());
  Serial.printf("  Task Count: %d\n", uxTaskGetNumberOfTasks());
  Serial.printf("  Core 0 Stack High Water Mark: %d\n", uxTaskGetStackHighWaterMark(NULL));
  Serial.printf("  Core 1 Stack High Water Mark: %d\n", uxTaskGetStackHighWaterMark(NULL));
}

void loop() {
  // Nothing to do in the loop
}

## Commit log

2024-05-17 Added rgb led control
2024-05-23 Moved LED Control out of power
2024-05-27 Draft relay module
2024-05-28 Relay Module added
2024-05-28 Schematic to PCB
2024-05-28 USB type c connector changed
2024-05-29 PCB update
2024-05-31 Relay module routing
2024-06-02 PCB routing
2024-06-03 Production Files Created
    [BOM_ESP32_RelayControl_PCB_ESP32_RelayControl_2024-06-03.xlsx, PickAndPlace_PCB_ESP32_RelayControl_2024-06-03.xlsx]
2024-06-04 Update pcb with acute angle to 45 degree
    [BOM_ESP32_RelayControl_PCB_ESP32_RelayControl_2024-06-03.xlsx, BOM_ESP32_RelayControl_PCB_ESP32_RelayControl_2024-06-04.xlsx, PickAndPlace_PCB_ESP32_RelayContr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]
2024-06-04 Updated readme file
    [1_ESP32_schematic.schdoc.schdoc, ESP32_RelayControl.pcbdoc]
2024-06-05 Updated silkscreen to v1.1
    [1_ESP32_schematic.schdoc.schdoc, BOM_ESP32_RelayControl_PCB_ESP32_RelayControl_2024-06-03.xlsx, BOM_ESP32_RelayControl_PCB_ESP32_RelayControl_2024-06-04.xlsx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]
2024-06-06 Minor chnage in trace for usb vbus
2024-06-06 Minor change in trace for usb vbus
2024-06-06 Added image of schematic and 3d
2024-06-10 Added my post graduate project to this repo
    [Mechanical.SchDoc, Sheet1.SchDoc, Sheet2.SchDoc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]
2024-06-10 Added schematic
2024-06-12 Correct power and ground for ldo and hi-link
    [BOM_ESP32_RelayControl_PCB_ESP32_RelayControl_2024-06-12.xlsx, PickAndPlace_PCB_ESP32_RelayControl_2024-06-12.xlsx]
2024-08-15 Added power supply sche
2024-08-16 Added usb schematic
2024-08-24 Added eFuse in powersupply
2024-08-26 Added programmer switch and changed screw terminal
2024-08-27 Added esp32 s3 wroom 1u
2024-08-29 Added 7inch touchscreen fpc connector
2024-09-07 Added RS485 circuit
2024-09-23 Added SPI Nand Flash 1GB
2024-09-24 Rearranged all schematic and added mosfet output control
2024-09-25 Added Mosfet digital output
2024-10-03 Adding Current to Voltage Convertor
2024-10-09 Added 12v buck convertor
2024-10-10 Removed OV, UV from power supply
    [BOM_Board1_GController_2024-10-10.xlsx]
2024-10-10 Undo of last changes
    [BOM_Board1_GController_2024-10-10.xlsx]
2024-10-13 Minor corrections on wiring
2024-10-14 Added links of datasheet and reference document in each schematics
2024-10-14 Corrections on powersupply
2024-10-15 Removed pull resistor from all i2c devices
2024-10-15 Updated cp2102 footprint
2024-10-15 Pin mapping updated
2024-10-16 Removed usb to uart schematic and replaced with d+ and d-
2024-10-20 PCD routing - power supply
2024-11-26 PCD power and ground plane
2024-12-01 PCB power and ground plane
    [BOM_Board1_GController_2024-11-30.xlsx, PickAndPlace_GController_2024-11-30.xlsx, TestPoint_GController_2024-11-30.xlsx]
2024-12-06 PCB is sent for production
    [BOM_Board1_GController_2024-11-30.xlsx, BOM_Board1_GController_2024-12-01.xlsx, BOM_Board1_GController_2024-12-03.xlsx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]
2024-12-19 Schematic updated
2024-12-21 Adding test arduino codes and libraries
2024-12-31 Uploaded board images
2025-01-01 Uploaded board layer images
